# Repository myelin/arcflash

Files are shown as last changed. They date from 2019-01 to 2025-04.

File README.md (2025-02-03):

# Arcflash

A board that plugs into all Acorn Archimedes, A3000, A5000 (with adapter), and
Risc PC (with adapter) machines, allowing OS updates without opening the
machine -- or even powering it down!

[Detailed design info](DESIGN.md)

[Stardot thread](https://stardot.org.uk/forums/viewtopic.php?f=16&t=16043)

Pictures
--------

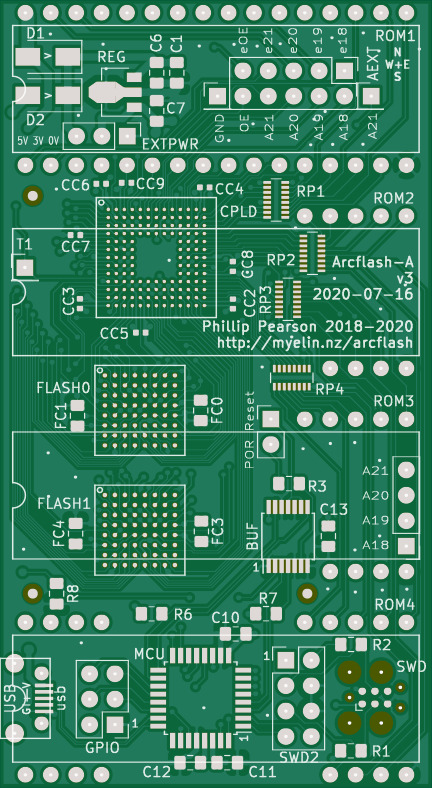
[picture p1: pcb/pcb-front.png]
PCB front


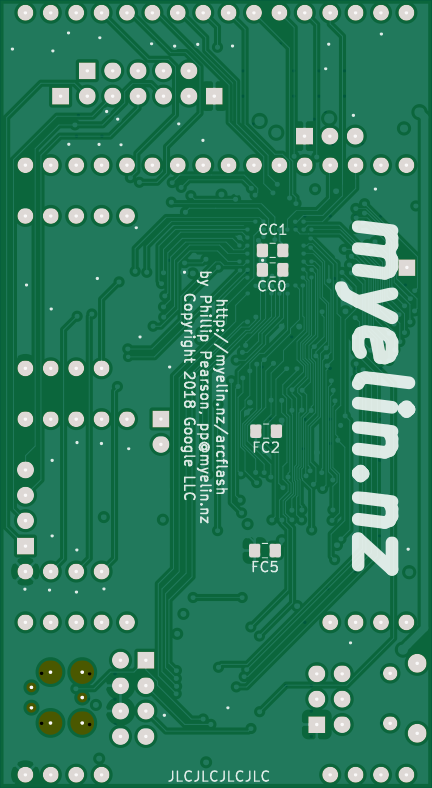
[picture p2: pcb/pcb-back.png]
PCB back


Assembly notes
--------------

For IC sockets, cut two 40-pin headers to make:

- one 2x16-pin header and one 2x4-pin headers
- four 5+4-pin headers and two 2-pin headers

Note from my employer
---------------------

This is not an officially supported Google product. This project is not
eligible for the [Google Open Source Software Vulnerability Rewards
Program](https://bughunters.google.com/open-source-security).

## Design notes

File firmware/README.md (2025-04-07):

# Firmware for Arcflash ATSAMD21E18A

This is the code that runs on the Arcflash's MCU.

It's built using the Arduino toolchain; originally using the Adafruit Circuit Playground Express variant, but now we have our own variant (see the hardware folder for details).

To build and upload, you'll need to [install arduino-cli](https://arduino.github.io/arduino-cli/installation/).

macOS: `brew install arduino-cli`

Ubuntu: `sudo apt install make; sudo snap install arduino-cli`

Run `make` for an incremental build or `make release` for a clean build.

Run `make upload` to build the code and upload it to a connected Arcflash board.

If you see "Platform not installed", "Error resolving FQBN", or an error finding a tool like `arm-none-eabi-g++`, update your cores:

~~~
arduino-cli --config-file arduino-cli.yaml core update-index
arduino-cli --config-file arduino-cli.yaml core install adafruit:samd
~~~

If you see linker errors ("Undefined reference to \`Uart::Uart(SERCOM\*, ...") on Windows, just rerun build_and_upload.py; this just seems to happen sometimes (?!)

> (2021-01-19) Note that arduino-cli 0.14.0 has a bug (*"Error during Upload: uploading error: cannot execute upload tool: fork/exec {runtime.tools.bossac-1.7.0-arduino3.path}/bossac: no such file or directory"* when it tries to upload the compiled code to the board), so if 0.15.0 isn't out yet, you'll need to:
>
> - On Windows and Linux, install a nightly build from the [arduino-cli site](https://arduino.github.io/arduino-cli/installation/)
> - On macOS, install from HEAD using Homebrew: `brew install --HEAD arduino-cli`

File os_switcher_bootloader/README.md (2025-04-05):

[Stardot thread](https://stardot.org.uk/forums/viewtopic.php?f=30&t=16420)

A bootloader that runs on the Archimedes machine and selects the OS based on
which function keys are pressed.  Also the start of a modern test ROM for 30
year old machines with possibly bad RAM or chips, or tracks that have been
eaten by leaking battery chemicals.

Getting started
---------------

Prerequisites:
- [GNU Arm Embedded Toolchain](https://developer.arm.com/downloads/-/gnu-rm) (GCC 9 dropped ARM2 support though, so you need 8-2019-q3-update)
- Python 3
- protobuf (on macOS: brew install protobuf)

On macOS: `brew install protobuf python`, and to de-quarantine the toolchain, `find /opt/gcc-arm-none-eabi-8-2019-q3-update/ -type f -perm +111 -exec xattr -d com.apple.quarantine {} \;`

On Ubuntu: `sudo apt install protobuf-compiler python3 python3-protobuf`

To build, run 'make clean all'.  This will generate switcher.rom, which can be
run on Arculator -- just put it in one of the riscos folders and set rom_set
appropriately.  (For example, if you save it as roms/riscos3/switcher.rom, you
want to have rom_set = 3 in arc.cfg.  Make sure there are no other ROM files
in the same folder.)

ROM structure
-------------

The ROM is designed to run on both Archimedes (26-bit ARMv2, MEMC) and Risc PC
(32-bit IOMD) machines.  The Archimedes code is "freestanding", handling all
IO etc itself, whereas the Risc PC code runs under a stripped-down RISC OS
build and uses RISC OS SWI commands for its UI, to access the NVRAM, etc.  To
make all this work, a number of images are concatenated to make the actual
ROM:

- 336k: RISC OS build, with modifications:
  - CPU test on startup, jumping to Archimedes bootloader if ARMv2 detected
  - No 3 second wait for special keys on boot
  - Instead of running the configured language module, run RPC bootloader
- 4 bytes: offset of RPC bootloader
- 4 bytes: offset of Arc bootloader
- Arc bootloader
- RPC bootloader

The Arc bootloader is almost but not quite position-independent code, so it's
built with a start address of 0x3854008 (Arc ROM area + 336k + 8 bytes), which
will need to be changed if the RISC OS image ever changes size.  The RPC
bootloader is copied to RAM by the final boot step in the RISC OS build, so
it's built with a start address of 0x8000.

Notes about bare metal programming for the Archimedes
-----------------------------------------------------

The initial entrypoint is \_start in start.s, which calls cstartup() in
cstartup.cc, which calls main_program() in main.cc.

The intention here is to compile everything with the latest arm-none-eabi-gcc,
rather than the ROOL DDE or GCCSDK.  It seems to be going OK so far; here are
some issues I've encountered:

- Needed to compile with -nostdlib, to avoid clashing with GCC's
  expectations for main() etc.

- Needed to compile with -fno-exceptions, otherwise the linker
  complains that it can't find \__aeabi_unwind_cpp_pr0.

- Needed to compile with -mno-thumb-interwork, otherwise the compiler
  generates "bx lr" instructions, which aren't in ARMv2.

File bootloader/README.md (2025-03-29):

# Bootloader for Arcflash ATSAMD21E18A

This is the bootloader for the Arcflash's MCU, built from [github.com/myelin/uf2-samdx1](https://github.com/myelin/uf2-samdx1).

To program into a freshly made or unresponsive Arcflash:

~~~
python3 -m pip install --user https://github.com/adafruit/Adafruit_Adalink/archive/master.zip
python3 -m adalink.main -v atsamd21g18 -p jlink -w -h bootloader-*.bin
~~~

To program into an Arcflash with a working bootloader, [install arduino-cli](https://arduino.github.io/arduino-cli/installation/) and run the following:

~~~
cp update-bootloader-*.ino bootloader.ino
arduino-cli compile --verbose --fqbn arduino:samd:adafruit_circuitplayground_m0
# Use /dev/ttyACM* (Linux) or COMn (Windows) here:
arduino-cli upload --verbose --fqbn arduino:samd:adafruit_circuitplayground_m0 --port /dev/tty.usbmodem*
~~~

To rebuild:

~~~
make clean build
~~~

To erase an unresponsive Arcflash, try this.  The `erase` command by itself won't work, as the UF2
bootloader locks the first 0x2000 bytes.

~~~
JLinkExe -device ATSAMD21G18 -if swd -speed 1000
connect
erase 0x2000,0x40000
~~~

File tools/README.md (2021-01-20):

# Arcflash tools

This folder contains example ROM build scripts for Arcflash.

First install the Python library:

~~~
(cd ../python_lib; python3 -m pip install --user -e .)
~~~

Now you can build a ROM and save it:

~~~
python3 make_arc_rom.py save myrom.bin
~~~

Or build and upload it to the Arcflash in one go:

~~~
python3 make_arc_rom.py upload
~~~

> (2021-01-19) Note that on macOS, with the first v3 Arcflash board to be built, with the latest bootloader and firmware, this seems to hang after uploading a few megabytes.  Unplugging and replugging the USB cable and rerunning should get it a bit further, and eventually you should get a "Done" message.  I can't reproduce this on Linux, and haven't tried on Windows yet.  `test_serial_comms.py` is a tester for this that forces the worst-case scenario (16MB of entirely new data) to debug this.

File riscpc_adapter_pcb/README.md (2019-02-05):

Adapter board to allow an "arcflash" A3000 ROM emulator to work on a Risc PC.

Pictures
--------

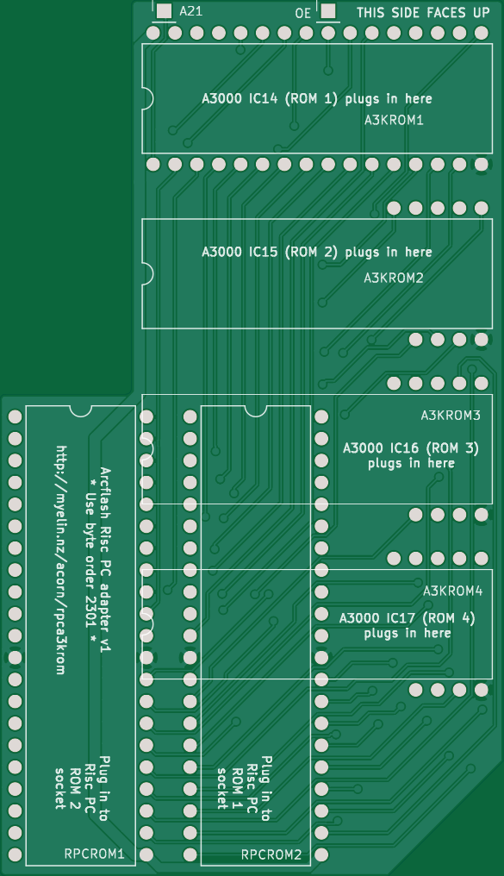
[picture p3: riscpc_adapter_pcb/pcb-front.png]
PCB front


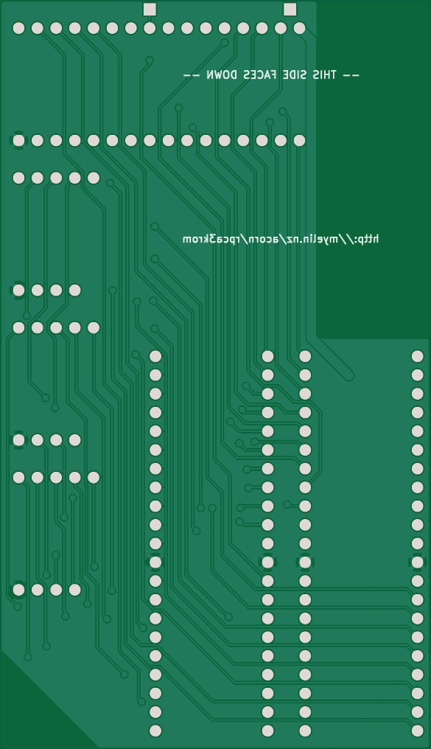
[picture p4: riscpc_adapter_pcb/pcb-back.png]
PCB back


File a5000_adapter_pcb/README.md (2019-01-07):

Adapter board to allow an "arcflash" A3000 ROM emulator to work on an A5000.

Pictures
--------

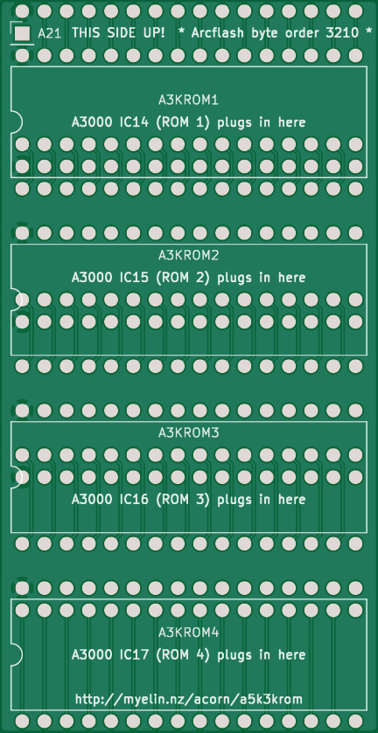
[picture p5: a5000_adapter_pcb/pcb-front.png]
PCB front


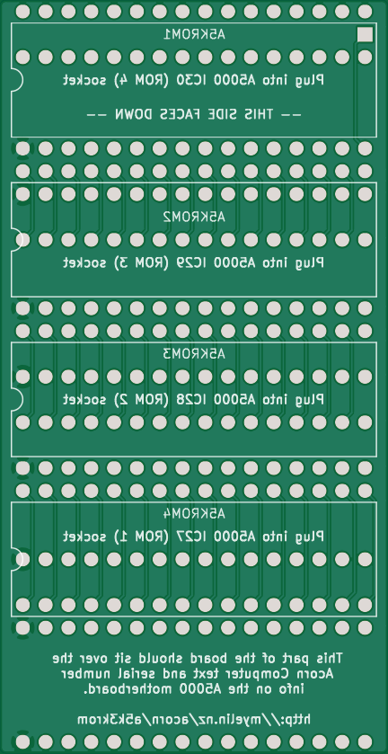
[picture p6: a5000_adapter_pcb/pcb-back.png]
PCB back


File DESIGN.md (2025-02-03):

# Arcflash Design Overview

Arcflash is a circuit board that plugs into the ROM sockets of many of the "Archimedes" series computers made by Acorn in the UK, circa 1990, running ARM2 or ARM3 processors (ARMv2 arch).
It allows uploading one or more operating system images over USB, and includes a bootloader to allow the user to select one to boot.

## Circuit design ([pcb/](pcb/))

PCB front

The OS images are stored on two 16 bit wide 8MB flash chips; `FLASH0` holds the lower two bytes of each word and `FLASH1` holds the high bytes.

A CPLD (`CPLD`) handles all the switching; it connects to the ROM socket address and data lines (via resistor packs RP1-4) and passes addresses through to the flash chips and data back to the data lines on the ROM sockets.

A microcontroller (`MCU`) provides the USB interface, so an attached computer can program OS images into the flash chips.

## CPLD gateware ([cpld/](cpld/))

The CPLD gateware's main function is to proxy the host's address bus (as seen on the ROM socket pins) over to the flash chips, and proxy data back to the host.

It also speaks a simple SPI protocol to allow the MCU to read and write from the flash, select the flash bank to expose to the host machine, and 

Finally, it listens for reads to certain "magic addresses", and implements a one-bit communication channel between the host and MCU. With proper timing, the host can bit-bang a slow serial connection.

The CPLD gateware is built using the (discontinued) Xilinx ISE 14.7 software.

## Host bootloader ([os_switcher_bootloader/](os_switcher_bootloader/))

The host bootloader runs as a bare-metal application.

It reads a proto containing information about all the OS images programmed into the flash, displays a menu, and forwards the user's OS selection to the microcontroller (over the bit-banged serial port).

See [this forum post](https://stardot.org.uk/forums/viewtopic.php?p=229976#p229976) for details on the code structure.

The host bootloader is compiled with gcc-arm-none-eabi version 8 or earlier (GCC 9 dropped ARMv2 support).

## MCU firmware ([firmware/](firmware/), [bootloader/](bootloader/))

The MCU firmware is mainly responsible for USB communication: it speaks a very simple text-based protocol that allows the remote driver software to program the flash.

It is also responsible for listening on a serial port for instructions from the host bootloader. When the user selects an OS to boot, the MCU firmware sends instructions to the CPLD to switch banks, then drives the system reset line to cause the host machine to reboot.

The MCU firmware is compiled compiled using the Arduino toolchain (using `arduino-cli`).

## Remote driver software ([python_lib/](python_lib/))

This code runs on an attached computer, to pack OS images into the correct format, and send them to an Arcflash board over USB.

The remote driver software is written in Python 3.

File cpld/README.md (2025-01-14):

# Arcflash CPLD RTL

This is the RTL for the Xilinx XC95144XL CPLD on the Arcflash board.

Build this using Xilinx ISE 14.7.  This is a discontinued product, but you can still download it.  I don't recommend using the Windows 10 version (which is a Linux VM running an old version of Oracle Linux).  If you're on Windows, use WSL2 and Ubuntu and install the Linux version instead.  To install the Linux version, google `xilinx ise 14.7 download` and download the *Full Installer for Linux* or the *Full DVD Single File Download Image*, untar somewhere, and run `./xsetup`.  If you get an error about `libncurses.so.5`, at least on Ubuntu Noble you can just `cd /usr/lib/x86_64-linux-gnu && ln -s libncurses.so.6 libncurses.so.5`, and the graphical installer will start up fine.

To build the `.svf` image: `make local`

Arcflash has no external JTAG connector; program the CPLD via the MCU: `make program`

To run the testbenches (the old Verilog one and the new Python/cocotb one), install Icarus Verilog and `cocotb`, and run: `make test2`

I run builds under Linux but test on macOS, so this means `brew install icarus-verilog gtkwave python3; python3 -m venv ~/ve; source ~/ve/bin/activate; pip3 install cocotb pytest; make test2`

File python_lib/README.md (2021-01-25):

# Arcflash

Arcflash is a flash ROM board for the Acorn Archimedes and Risc PC computers.

This is the Python support library, which lets you build your own flash
images, and program them into the memory on an Arcflash board connected over
USB.

Project homepage: http://myelin.nz/arcflash

Python library code: https://github.com/google/myelin-acorn-electron-hardware/tree/main/a3000_rom_emulator/python_lib

## Getting started

First, install the library with `pip install arcflash`.

Next, copy the following example and save it as `myrom.py`.  This assumes you have the [3QD classic rom archive](http://www.riscos.com/shop/products/101/index.htm) unpacked in a folder called `classics`.

~~~~
from arcflash.rombuild import *

FlashImage(
    roms=[
        ROM(
            tag="arthur030",
            name="Arthur 0.30",
            files=['classics/Arthur/Arthur_030'],
            size=_1M,
            cmos="arthur030",
            ),
        ROM(
            tag="arthur120",
            name="Arthur 1.20",
            files=['classics/Arthur/Arthur_120'],
            size=_1M,
            cmos="arthur120",
            ),
        ROM(
            tag="riscos201",
            name="RISC OS 2.01",
            files=['classics/RISC_OS_2/ROM_201'],
            size=_1M,
            cmos="riscos201",
        ),
        ROM(
            tag="riscos311",
            name="RISC OS 3.11",
            files=['classics/RISC_OS_3/ROM_311'],
            size=_2M,
            cmos="riscos311",
            ),
    ],
)
~~~~

Now run `python myrom.py save rom.bin` to build the flash image and save it as rom.bin.  This file should be 16MB long.  If that worked, plug in your Arcflash board and run `python myrom.py upload` to build and upload the flash image.

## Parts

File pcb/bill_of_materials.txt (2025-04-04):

Identifier	Value	Description	KiCad package	LCSC part
RP1	Pack of 8 x isolated 68R resistors	8 x 68R pack; https://www.digikey.com/product-detail/en/panasonic-electronic-components/EXB-2HV680JV/Y1680CT-ND/285367	Resistor_SMD:R_Array_Convex_8x0602	
RP2	Pack of 8 x isolated 68R resistors	8 x 68R pack; https://www.digikey.com/product-detail/en/panasonic-electronic-components/EXB-2HV680JV/Y1680CT-ND/285367	Resistor_SMD:R_Array_Convex_8x0602	
RP3	Pack of 8 x isolated 68R resistors	8 x 68R pack; https://www.digikey.com/product-detail/en/panasonic-electronic-components/EXB-2HV680JV/Y1680CT-ND/285367	Resistor_SMD:R_Array_Convex_8x0602	
RP4	Pack of 8 x isolated 68R resistors	8 x 68R pack; https://www.digikey.com/product-detail/en/panasonic-electronic-components/EXB-2HV680JV/Y1680CT-ND/285367	Resistor_SMD:R_Array_Convex_8x0602	
CC2	100n	Capacitor 0402: 100n	Capacitor_SMD:C_0402_1005Metric	
CC3	100n	Capacitor 0402: 100n	Capacitor_SMD:C_0402_1005Metric	
CC4	100n	Capacitor 0402: 100n	Capacitor_SMD:C_0402_1005Metric	
CC5	100n	Capacitor 0402: 100n	Capacitor_SMD:C_0402_1005Metric	
CC6	100n	Capacitor 0402: 100n	Capacitor_SMD:C_0402_1005Metric	
CC7	100n	Capacitor 0402: 100n	Capacitor_SMD:C_0402_1005Metric	
CC8	100n	Capacitor 0402: 100n	Capacitor_SMD:C_0402_1005Metric	
CC9	100n	Capacitor 0402: 100n	Capacitor_SMD:C_0402_1005Metric	
C10	100n	Capacitor 0805: 100n	Capacitor_SMD:C_0805_2012Metric_Pad1.15x1.40mm_HandSolder	C49678
C11	100n	Capacitor 0805: 100n	Capacitor_SMD:C_0805_2012Metric_Pad1.15x1.40mm_HandSolder	C49678
C13	100n	Capacitor 0805: 100n	Capacitor_SMD:C_0805_2012Metric_Pad1.15x1.40mm_HandSolder	C49678
FC0	100n	Capacitor 0805: 100n	Capacitor_SMD:C_0805_2012Metric_Pad1.15x1.40mm_HandSolder	C49678
FC1	100n	Capacitor 0805: 100n	Capacitor_SMD:C_0805_2012Metric_Pad1.15x1.40mm_HandSolder	C49678
FC3	100n	Capacitor 0805: 100n	Capacitor_SMD:C_0805_2012Metric_Pad1.15x1.40mm_HandSolder	C49678
FC4	100n	Capacitor 0805: 100n	Capacitor_SMD:C_0805_2012Metric_Pad1.15x1.40mm_HandSolder	C49678
CC0	100n NF	Capacitor 0805: 100n NF	Capacitor_SMD:C_0805_2012Metric_Pad1.15x1.40mm_HandSolder	
CC1	100n NF	Capacitor 0805: 100n NF	Capacitor_SMD:C_0805_2012Metric_Pad1.15x1.40mm_HandSolder	
FC2	100n NF	Capacitor 0805: 100n NF	Capacitor_SMD:C_0805_2012Metric_Pad1.15x1.40mm_HandSolder	
FC5	100n NF	Capacitor 0805: 100n NF	Capacitor_SMD:C_0805_2012Metric_Pad1.15x1.40mm_HandSolder	
C1	10u	Capacitor 0805: 10u	Capacitor_SMD:C_0805_2012Metric_Pad1.15x1.40mm_HandSolder	
C6	1u	Capacitor 0805: 1u	Capacitor_SMD:C_0805_2012Metric_Pad1.15x1.40mm_HandSolder	C28323
C7	1u	Capacitor 0805: 1u	Capacitor_SMD:C_0805_2012Metric_Pad1.15x1.40mm_HandSolder	C28323
C12	1u	Capacitor 0805: 1u	Capacitor_SMD:C_0805_2012Metric_Pad1.15x1.40mm_HandSolder	C28323
D1	S1ATR	Diode Rectifier; https://www.digikey.com/products/en?keywords=1655-1502-1-ND	Diode_SMD:D_SMA	
D2	S1ATR NF	Diode Rectifier; https://www.digikey.com/products/en?keywords=1655-1502-1-ND	Diode_SMD:D_SMA	
MCU	ATSAMD21E18A-AU	IC ARM MCU; https://www.digikey.com/products/en?keywords=ATSAMD21E18A-AU-ND	Package_QFP:TQFP-32_7x7mm_P0.8mm	
CPLD	XC95144XL-10CSG144	IC CPLD Xilinx 144MC	myelin-kicad:xilinx_csg144	
REG	AP7365-33YG-XX	IC LDO 3.3V regulator; https://www.digikey.com/products/en?keywords=AP7365-33YG-13DICT-ND	Package_TO_SOT_SMD:SOT-89-3	
BUF	74LVC125PW	IC buffer 4-bit OC LVT; https://www.digikey.com/product-detail/en/74LVT125PW%2c118/1727-3115-1-ND	Package_SO:TSSOP-14_4.4x5mm_P0.65mm	
FLASH0	S29GL064S70DHI010	IC flash 64Mbit; https://www.digikey.com/products/en?keywords=2015-S29GL064S70DHI010-ND	myelin-kicad:cypress_lae064_fbga	
FLASH1	S29GL064S70DHI010	IC flash 64Mbit; https://www.digikey.com/products/en?keywords=2015-S29GL064S70DHI010-ND	myelin-kicad:cypress_lae064_fbga	
ROM1	ROM header	Pin adapter to emulate a 600mil 32-pin DIP; round pin header strip from Aliexpress	myelin-kicad:dip32_rom	
ROM2	ROM header	Pin adapter to emulate a 600mil 32-pin DIP; round pin header strip from Aliexpress	myelin-kicad:dip32_rom_data_only	
ROM3	ROM header	Pin adapter to emulate a 600mil 32-pin DIP; round pin header strip from Aliexpress	myelin-kicad:dip32_rom_data_only	
ROM4	ROM header	Pin adapter to emulate a 600mil 32-pin DIP; round pin header strip from Aliexpress	myelin-kicad:dip32_rom_data_only	
AEXT2	Addresses	Pin header	Connector_PinHeader_2.54mm:PinHeader_1x04_P2.54mm_Vertical	
AEXT	Extras	Pin header	Connector_PinHeader_2.54mm:PinHeader_2x05_P2.54mm_Vertical	
AEXTGND	Ground	Pin header	Connector_PinHeader_2.54mm:PinHeader_1x01_P2.54mm_Vertical	
T1	rom_5V	Pin header	Connector_PinHeader_2.54mm:PinHeader_1x01_P2.54mm_Vertical	
A21	rom_A19	Pin header	Connector_PinHeader_2.54mm:PinHeader_1x01_P2.54mm_Vertical	
RESET	reset/POR	Pin header - 1x2 0.1 inch male	Connector_PinHeader_2.54mm:PinHeader_1x02_P2.54mm_Vertical	
GPIO	gpio	Pin header NF	Connector_PinHeader_2.54mm:PinHeader_2x03_P2.54mm_Vertical	
SWD2	swd	Pin header NF	Connector_PinHeader_2.54mm:PinHeader_2x04_P2.54mm_Vertical	
EXTPWR	ext pwr	Pin header NF - 1x3 0.1 inch male	Connector_PinHeader_2.54mm:PinHeader_1x03_P2.54mm_Vertical	
R3	100R	Resistor 0805: 100R	Resistor_SMD:R_0805_2012Metric_Pad1.15x1.40mm_HandSolder	
R1	10k	Resistor 0805: 10k	Resistor_SMD:R_0805_2012Metric_Pad1.15x1.40mm_HandSolder	C17414
R6	10k	Resistor 0805: 10k	Resistor_SMD:R_0805_2012Metric_Pad1.15x1.40mm_HandSolder	C17414
R7	10k	Resistor 0805: 10k	Resistor_SMD:R_0805_2012Metric_Pad1.15x1.40mm_HandSolder	C17414
R8	10k	Resistor 0805: 10k	Resistor_SMD:R_0805_2012Metric_Pad1.15x1.40mm_HandSolder	C17414
R2	1k	Resistor 0805: 1k	Resistor_SMD:R_0805_2012Metric_Pad1.15x1.40mm_HandSolder	C17513
USB	usb	Socket Micro USB, Molex 1050170001; https://www.digikey.com/products/en?keywords=WM1399CT-ND	myelin-kicad:micro_usb_b_smd_molex

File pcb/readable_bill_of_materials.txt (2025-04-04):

This is the human-readable bill of materials.
See bill_of_materials.txt for a terser version suitable for spreadsheet import.

RP1
- Value: Pack of 8 x isolated 68R resistors
- Description: 8 x 68R pack; https://www.digikey.com/product-detail/en/panasonic-electronic-components/EXB-2HV680JV/Y1680CT-ND/285367
- KiCad package: Resistor_SMD:R_Array_Convex_8x0602

RP2
- Value: Pack of 8 x isolated 68R resistors
- Description: 8 x 68R pack; https://www.digikey.com/product-detail/en/panasonic-electronic-components/EXB-2HV680JV/Y1680CT-ND/285367
- KiCad package: Resistor_SMD:R_Array_Convex_8x0602

RP3
- Value: Pack of 8 x isolated 68R resistors
- Description: 8 x 68R pack; https://www.digikey.com/product-detail/en/panasonic-electronic-components/EXB-2HV680JV/Y1680CT-ND/285367
- KiCad package: Resistor_SMD:R_Array_Convex_8x0602

RP4
- Value: Pack of 8 x isolated 68R resistors
- Description: 8 x 68R pack; https://www.digikey.com/product-detail/en/panasonic-electronic-components/EXB-2HV680JV/Y1680CT-ND/285367
- KiCad package: Resistor_SMD:R_Array_Convex_8x0602

CC2
- Value: 100n
- Description: Capacitor 0402: 100n
- KiCad package: Capacitor_SMD:C_0402_1005Metric

CC3
- Value: 100n
- Description: Capacitor 0402: 100n
- KiCad package: Capacitor_SMD:C_0402_1005Metric

CC4
- Value: 100n
- Description: Capacitor 0402: 100n
- KiCad package: Capacitor_SMD:C_0402_1005Metric

CC5
- Value: 100n
- Description: Capacitor 0402: 100n
- KiCad package: Capacitor_SMD:C_0402_1005Metric

CC6
- Value: 100n
- Description: Capacitor 0402: 100n
- KiCad package: Capacitor_SMD:C_0402_1005Metric

CC7
- Value: 100n
- Description: Capacitor 0402: 100n
- KiCad package: Capacitor_SMD:C_0402_1005Metric

CC8
- Value: 100n
- Description: Capacitor 0402: 100n
- KiCad package: Capacitor_SMD:C_0402_1005Metric

CC9
- Value: 100n
- Description: Capacitor 0402: 100n
- KiCad package: Capacitor_SMD:C_0402_1005Metric

C10
- Value: 100n
- Description: Capacitor 0805: 100n
- KiCad package: Capacitor_SMD:C_0805_2012Metric_Pad1.15x1.40mm_HandSolder

C11
- Value: 100n
- Description: Capacitor 0805: 100n
- KiCad package: Capacitor_SMD:C_0805_2012Metric_Pad1.15x1.40mm_HandSolder

C13
- Value: 100n
- Description: Capacitor 0805: 100n
- KiCad package: Capacitor_SMD:C_0805_2012Metric_Pad1.15x1.40mm_HandSolder

FC0
- Value: 100n
- Description: Capacitor 0805: 100n
- KiCad package: Capacitor_SMD:C_0805_2012Metric_Pad1.15x1.40mm_HandSolder

FC1
- Value: 100n
- Description: Capacitor 0805: 100n
- KiCad package: Capacitor_SMD:C_0805_2012Metric_Pad1.15x1.40mm_HandSolder

FC3
- Value: 100n
- Description: Capacitor 0805: 100n
- KiCad package: Capacitor_SMD:C_0805_2012Metric_Pad1.15x1.40mm_HandSolder

FC4
- Value: 100n
- Description: Capacitor 0805: 100n
- KiCad package: Capacitor_SMD:C_0805_2012Metric_Pad1.15x1.40mm_HandSolder

CC0
- Value: 100n NF
- Description: Capacitor 0805: 100n NF
- KiCad package: Capacitor_SMD:C_0805_2012Metric_Pad1.15x1.40mm_HandSolder

CC1
- Value: 100n NF
- Description: Capacitor 0805: 100n NF
- KiCad package: Capacitor_SMD:C_0805_2012Metric_Pad1.15x1.40mm_HandSolder

FC2
- Value: 100n NF
- Description: Capacitor 0805: 100n NF
- KiCad package: Capacitor_SMD:C_0805_2012Metric_Pad1.15x1.40mm_HandSolder

FC5
- Value: 100n NF
- Description: Capacitor 0805: 100n NF
- KiCad package: Capacitor_SMD:C_0805_2012Metric_Pad1.15x1.40mm_HandSolder

C1
- Value: 10u
- Description: Capacitor 0805: 10u
- KiCad package: Capacitor_SMD:C_0805_2012Metric_Pad1.15x1.40mm_HandSolder

C6
- Value: 1u
- Description: Capacitor 0805: 1u
- KiCad package: Capacitor_SMD:C_0805_2012Metric_Pad1.15x1.40mm_HandSolder

C7
- Value: 1u
- Description: Capacitor 0805: 1u
- KiCad package: Capacitor_SMD:C_0805_2012Metric_Pad1.15x1.40mm_HandSolder

C12
- Value: 1u
- Description: Capacitor 0805: 1u
- KiCad package: Capacitor_SMD:C_0805_2012Metric_Pad1.15x1.40mm_HandSolder

D1
- Value: S1ATR
- Description: Diode Rectifier; https://www.digikey.com/products/en?keywords=1655-1502-1-ND
- KiCad package: Diode_SMD:D_SMA

D2
- Value: S1ATR NF
- Description: Diode Rectifier; https://www.digikey.com/products/en?keywords=1655-1502-1-ND
- KiCad package: Diode_SMD:D_SMA

MCU
- Value: ATSAMD21E18A-AU
- Description: IC ARM MCU; https://www.digikey.com/products/en?keywords=ATSAMD21E18A-AU-ND
- KiCad package: Package_QFP:TQFP-32_7x7mm_P0.8mm

CPLD
- Value: XC95144XL-10CSG144
- Description: IC CPLD Xilinx 144MC
- KiCad package: myelin-kicad:xilinx_csg144

REG
- Value: AP7365-33YG-XX
- Description: IC LDO 3.3V regulator; https://www.digikey.com/products/en?keywords=AP7365-33YG-13DICT-ND
- KiCad package: Package_TO_SOT_SMD:SOT-89-3

BUF
- Value: 74LVC125PW
- Description: IC buffer 4-bit OC LVT; https://www.digikey.com/product-detail/en/74LVT125PW%2c118/1727-3115-1-ND
- KiCad package: Package_SO:TSSOP-14_4.4x5mm_P0.65mm

FLASH0
- Value: S29GL064S70DHI010
- Description: IC flash 64Mbit; https://www.digikey.com/products/en?keywords=2015-S29GL064S70DHI010-ND
- KiCad package: myelin-kicad:cypress_lae064_fbga

FLASH1
- Value: S29GL064S70DHI010
- Description: IC flash 64Mbit; https://www.digikey.com/products/en?keywords=2015-S29GL064S70DHI010-ND
- KiCad package: myelin-kicad:cypress_lae064_fbga

ROM1
- Value: ROM header
- Description: Pin adapter to emulate a 600mil 32-pin DIP; round pin header strip from Aliexpress
- KiCad package: myelin-kicad:dip32_rom

ROM2
- Value: ROM header
- Description: Pin adapter to emulate a 600mil 32-pin DIP; round pin header strip from Aliexpress
- KiCad package: myelin-kicad:dip32_rom_data_only

ROM3
- Value: ROM header
- Description: Pin adapter to emulate a 600mil 32-pin DIP; round pin header strip from Aliexpress
- KiCad package: myelin-kicad:dip32_rom_data_only

ROM4
- Value: ROM header
- Description: Pin adapter to emulate a 600mil 32-pin DIP; round pin header strip from Aliexpress
- KiCad package: myelin-kicad:dip32_rom_data_only

AEXT2
- Value: Addresses
- Description: Pin header
- KiCad package: Connector_PinHeader_2.54mm:PinHeader_1x04_P2.54mm_Vertical

AEXT
- Value: Extras
- Description: Pin header
- KiCad package: Connector_PinHeader_2.54mm:PinHeader_2x05_P2.54mm_Vertical

AEXTGND
- Value: Ground
- Description: Pin header
- KiCad package: Connector_PinHeader_2.54mm:PinHeader_1x01_P2.54mm_Vertical

T1
- Value: rom_5V
- Description: Pin header
- KiCad package: Connector_PinHeader_2.54mm:PinHeader_1x01_P2.54mm_Vertical

A21
- Value: rom_A19
- Description: Pin header
- KiCad package: Connector_PinHeader_2.54mm:PinHeader_1x01_P2.54mm_Vertical

RESET
- Value: reset/POR
- Description: Pin header - 1x2 0.1 inch male
- KiCad package: Connector_PinHeader_2.54mm:PinHeader_1x02_P2.54mm_Vertical

GPIO
- Value: gpio
- Description: Pin header NF
- KiCad package: Connector_PinHeader_2.54mm:PinHeader_2x03_P2.54mm_Vertical

SWD2
- Value: swd
- Description: Pin header NF
- KiCad package: Connector_PinHeader_2.54mm:PinHeader_2x04_P2.54mm_Vertical

EXTPWR
- Value: ext pwr
- Description: Pin header NF - 1x3 0.1 inch male
- KiCad package: Connector_PinHeader_2.54mm:PinHeader_1x03_P2.54mm_Vertical

R3
- Value: 100R
- Description: Resistor 0805: 100R
- KiCad package: Resistor_SMD:R_0805_2012Metric_Pad1.15x1.40mm_HandSolder

R1
- Value: 10k
- Description: Resistor 0805: 10k
- KiCad package: Resistor_SMD:R_0805_2012Metric_Pad1.15x1.40mm_HandSolder

R6
- Value: 10k
- Description: Resistor 0805: 10k
- KiCad package: Resistor_SMD:R_0805_2012Metric_Pad1.15x1.40mm_HandSolder

R7
- Value: 10k
- Description: Resistor 0805: 10k
- KiCad package: Resistor_SMD:R_0805_2012Metric_Pad1.15x1.40mm_HandSolder

R8
- Value: 10k
- Description: Resistor 0805: 10k
- KiCad package: Resistor_SMD:R_0805_2012Metric_Pad1.15x1.40mm_HandSolder

R2
- Value: 1k
- Description: Resistor 0805: 1k
- KiCad package: Resistor_SMD:R_0805_2012Metric_Pad1.15x1.40mm_HandSolder

USB
- Value: usb
- Description: Socket Micro USB, Molex 1050170001; https://www.digikey.com/products/en?keywords=WM1399CT-ND
- KiCad package: myelin-kicad:micro_usb_b_smd_molex

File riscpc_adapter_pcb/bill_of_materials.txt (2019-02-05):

Identifier	Value	Description	KiCad package
A21			Connector_PinHeader_2.54mm:PinHeader_1x01_P2.54mm_Vertical
A3KROM1	ROM header	Adapter to emulate a 600mil 32-pin DIP, e.g. Digikey ???	myelin-kicad:dip32_rom
A3KROM2	ROM header	Adapter to emulate a 600mil 32-pin DIP, e.g. Digikey ???	myelin-kicad:dip32_rom_data_only
A3KROM3	ROM header	Adapter to emulate a 600mil 32-pin DIP, e.g. Digikey ???	myelin-kicad:dip32_rom_data_only
A3KROM4	ROM header	Adapter to emulate a 600mil 32-pin DIP, e.g. Digikey ???	myelin-kicad:dip32_rom_data_only
OE			Connector_PinHeader_2.54mm:PinHeader_1x01_P2.54mm_Vertical
RPCROM1	ROM header	Adapter to emulate a 600mil 42-pin DIP, e.g. Digikey ???	myelin-kicad:dip42_rom
RPCROM2	ROM header	Adapter to emulate a 600mil 42-pin DIP, e.g. Digikey ???	myelin-kicad:dip42_rom

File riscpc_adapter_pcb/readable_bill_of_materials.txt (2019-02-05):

This is the human-readable bill of materials.
See bill_of_materials.txt for a terser version suitable for spreadsheet import.

A21
- Value: 
- Description: 
- KiCad package: Connector_PinHeader_2.54mm:PinHeader_1x01_P2.54mm_Vertical

A3KROM1
- Value: ROM header
- Description: Adapter to emulate a 600mil 32-pin DIP, e.g. Digikey ???
- KiCad package: myelin-kicad:dip32_rom

A3KROM2
- Value: ROM header
- Description: Adapter to emulate a 600mil 32-pin DIP, e.g. Digikey ???
- KiCad package: myelin-kicad:dip32_rom_data_only

A3KROM3
- Value: ROM header
- Description: Adapter to emulate a 600mil 32-pin DIP, e.g. Digikey ???
- KiCad package: myelin-kicad:dip32_rom_data_only

A3KROM4
- Value: ROM header
- Description: Adapter to emulate a 600mil 32-pin DIP, e.g. Digikey ???
- KiCad package: myelin-kicad:dip32_rom_data_only

OE
- Value: 
- Description: 
- KiCad package: Connector_PinHeader_2.54mm:PinHeader_1x01_P2.54mm_Vertical

RPCROM1
- Value: ROM header
- Description: Adapter to emulate a 600mil 42-pin DIP, e.g. Digikey ???
- KiCad package: myelin-kicad:dip42_rom

RPCROM2
- Value: ROM header
- Description: Adapter to emulate a 600mil 42-pin DIP, e.g. Digikey ???
- KiCad package: myelin-kicad:dip42_rom

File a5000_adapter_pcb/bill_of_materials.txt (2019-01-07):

Identifier	Value	Description	KiCad package
A21			Connector_PinHeader_2.54mm:PinHeader_1x01_P2.54mm_Vertical
A3KROM1	ROM header	Adapter to emulate a 600mil 32-pin DIP, e.g. Digikey ???	myelin-kicad:dip32_rom
A3KROM2	ROM header	Adapter to emulate a 600mil 32-pin DIP, e.g. Digikey ???	myelin-kicad:dip32_rom
A3KROM3	ROM header	Adapter to emulate a 600mil 32-pin DIP, e.g. Digikey ???	myelin-kicad:dip32_rom
A3KROM4	ROM header	Adapter to emulate a 600mil 32-pin DIP, e.g. Digikey ???	myelin-kicad:dip32_rom
A5KROM1	ROM header	Adapter to emulate a 600mil 32-pin DIP, e.g. Digikey ???	myelin-kicad:dip32_rom_bottom
A5KROM2	ROM header	Adapter to emulate a 600mil 32-pin DIP, e.g. Digikey ???	myelin-kicad:dip32_rom_bottom
A5KROM3	ROM header	Adapter to emulate a 600mil 32-pin DIP, e.g. Digikey ???	myelin-kicad:dip32_rom_bottom
A5KROM4	ROM header	Adapter to emulate a 600mil 32-pin DIP, e.g. Digikey ???	myelin-kicad:dip32_rom_bottom

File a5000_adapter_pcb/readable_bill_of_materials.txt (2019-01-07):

This is the human-readable bill of materials.
See bill_of_materials.txt for a terser version suitable for spreadsheet import.

A21
- Value: 
- Description: 
- KiCad package: Connector_PinHeader_2.54mm:PinHeader_1x01_P2.54mm_Vertical

A3KROM1
- Value: ROM header
- Description: Adapter to emulate a 600mil 32-pin DIP, e.g. Digikey ???
- KiCad package: myelin-kicad:dip32_rom

A3KROM2
- Value: ROM header
- Description: Adapter to emulate a 600mil 32-pin DIP, e.g. Digikey ???
- KiCad package: myelin-kicad:dip32_rom

A3KROM3
- Value: ROM header
- Description: Adapter to emulate a 600mil 32-pin DIP, e.g. Digikey ???
- KiCad package: myelin-kicad:dip32_rom

A3KROM4
- Value: ROM header
- Description: Adapter to emulate a 600mil 32-pin DIP, e.g. Digikey ???
- KiCad package: myelin-kicad:dip32_rom

A5KROM1
- Value: ROM header
- Description: Adapter to emulate a 600mil 32-pin DIP, e.g. Digikey ???
- KiCad package: myelin-kicad:dip32_rom_bottom

A5KROM2
- Value: ROM header
- Description: Adapter to emulate a 600mil 32-pin DIP, e.g. Digikey ???
- KiCad package: myelin-kicad:dip32_rom_bottom

A5KROM3
- Value: ROM header
- Description: Adapter to emulate a 600mil 32-pin DIP, e.g. Digikey ???
- KiCad package: myelin-kicad:dip32_rom_bottom

A5KROM4
- Value: ROM header
- Description: Adapter to emulate a 600mil 32-pin DIP, e.g. Digikey ???
- KiCad package: myelin-kicad:dip32_rom_bottom

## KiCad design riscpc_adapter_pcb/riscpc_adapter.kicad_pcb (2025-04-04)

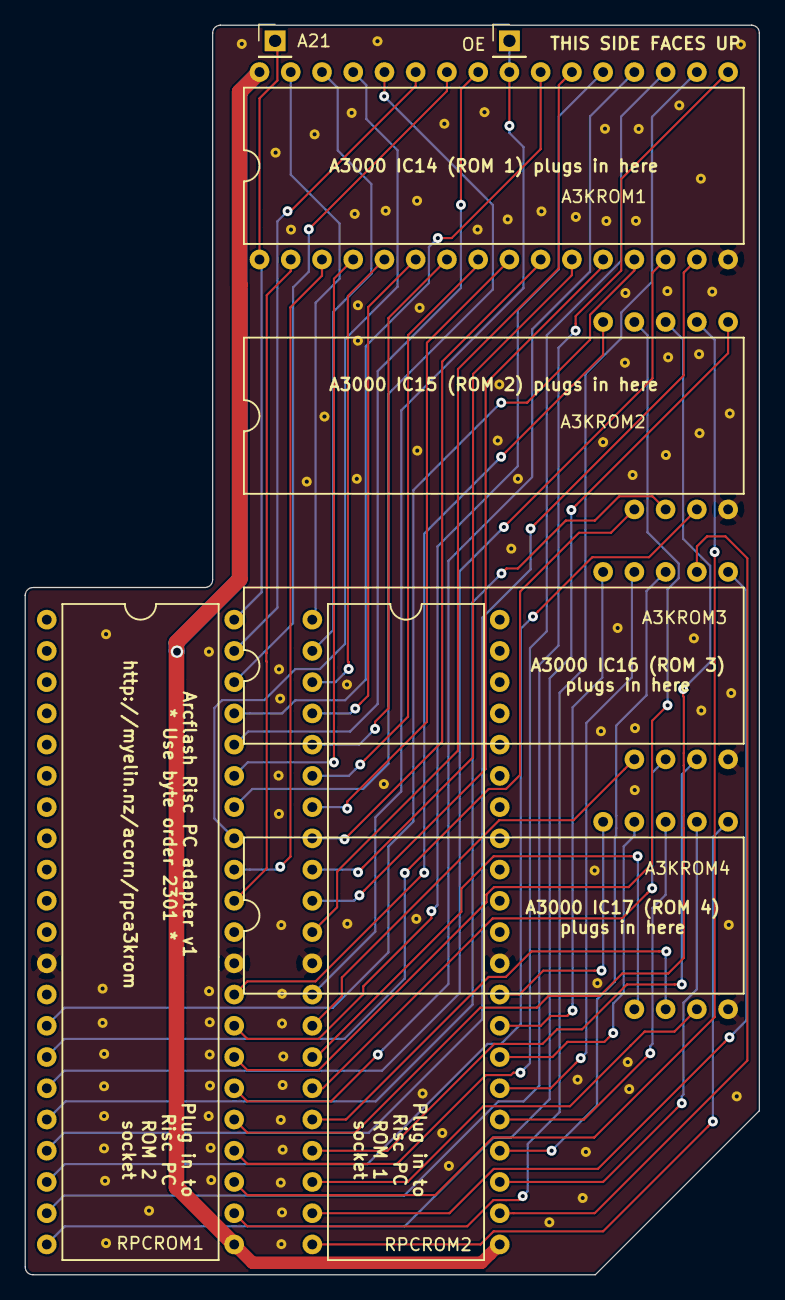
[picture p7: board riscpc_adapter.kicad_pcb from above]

Board: 2 copper layers, 59.7 x 101.6 mm, 108 parts (0 on the bottom side), 56 nets.

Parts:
A3KROM1: ROM header; dip32_rom
A3KROM2, A3KROM3, A3KROM4: ROM header; dip32_rom_data_only
A21: PinHeader_1x01_P2.54mm_Vertical
OE: PinHeader_1x01_P2.54mm_Vertical
RPCROM1, RPCROM2: ROM header; dip42_rom
staple_single1, staple_single2, staple_single3, staple_single4, staple_single5, staple_single6, staple_single7, staple_single8, staple_single9, staple_single10, staple_single11, staple_single12, staple_single13, staple_single14, staple_single15, staple_single16, staple_single17, staple_single18, staple_single19, staple_single20, staple_single21, staple_single22, staple_single23, staple_single24, staple_single25, staple_single26, staple_single27, staple_single28, staple_single29, staple_single30, staple_single31, staple_single32, staple_single33, staple_single34, staple_single35, staple_single36, staple_single37, staple_single38, staple_single39, staple_single40, staple_single41, staple_single42, staple_single43, staple_single44, staple_single45, staple_single46, staple_single47, staple_single48, staple_single49, staple_single50, staple_single51, staple_single52, staple_single53, staple_single54, staple_single55, staple_single56, staple_single57, staple_single58, staple_single59, staple_single60, staple_single61, staple_single62, staple_single63, staple_single64, staple_single65, staple_single66, staple_single67, staple_single68, staple_single69, staple_single70, staple_single71, staple_single72, staple_single73, staple_single74, staple_single75, staple_single76, staple_single77, staple_single78, staple_single79, staple_single80, staple_single81, staple_single82, staple_single83, staple_single84, staple_single85, staple_single86, staple_single87, staple_single88, staple_single89, staple_single90, staple_single91, staple_single92, staple_single93, staple_single94, staple_single95, staple_single96, staple_single97, staple_single98, staple_single99, staple_single100: via_single

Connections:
5V: A3KROM1.32, RPCROM1.22, RPCROM2.22
A0: A3KROM1.12, RPCROM2.10
A1: A3KROM1.11, RPCROM2.9
A2: A3KROM1.10, RPCROM2.8
A3: A3KROM1.9, RPCROM2.7
A4: A3KROM1.8, RPCROM2.6
A5: A3KROM1.7, RPCROM2.5
A6: A3KROM1.6, RPCROM2.4
A7: A3KROM1.5, RPCROM2.3
A8: A3KROM1.27, RPCROM1.41
A9: A3KROM1.26, RPCROM1.40
A10: A3KROM1.23, RPCROM1.39
A11: A3KROM1.25, RPCROM1.38
A12: A3KROM1.4, RPCROM1.37
A13: A3KROM1.28, RPCROM1.36
A14: A3KROM1.29, RPCROM1.35
A15: A3KROM1.3, RPCROM1.34
A16: A3KROM1.2, RPCROM1.33
A17: A3KROM1.30, RPCROM2.2
A18: A3KROM1.31, RPCROM2.1
A19: A3KROM1.1, A21.1, RPCROM1.42
D0: A3KROM1.13, RPCROM1.14
D1: A3KROM1.14, RPCROM1.16
D2: A3KROM1.15, RPCROM1.18
D3: A3KROM1.17, RPCROM1.20
D4: A3KROM1.18, RPCROM1.23
D5: A3KROM1.19, RPCROM1.25
D6: A3KROM1.20, RPCROM1.27
D7: A3KROM1.21, RPCROM1.29
D8: A3KROM2.13, RPCROM1.15
D9: A3KROM2.14, RPCROM1.17
D10: A3KROM2.15, RPCROM1.19
D11: A3KROM2.17, RPCROM1.21
D12: A3KROM2.18, RPCROM1.24
D13: A3KROM2.19, RPCROM1.26
D14: A3KROM2.20, RPCROM1.28
D15: A3KROM2.21, RPCROM1.30
D16: A3KROM3.13, RPCROM2.14
D17: A3KROM3.14, RPCROM2.16
D18: A3KROM3.15, RPCROM2.18
D19: A3KROM3.17, RPCROM2.20
D20: A3KROM3.18, RPCROM2.23
D21: A3KROM3.19, RPCROM2.25
D22: A3KROM3.20, RPCROM2.27
D23: A3KROM3.21, RPCROM2.29
D24: A3KROM4.13, RPCROM2.15
D25: A3KROM4.14, RPCROM2.17
D26: A3KROM4.15, RPCROM2.19
D27: A3KROM4.17, RPCROM2.21
D28: A3KROM4.18, RPCROM2.24
D29: A3KROM4.19, RPCROM2.26
D30: A3KROM4.20, RPCROM2.28
D31: A3KROM4.21, RPCROM2.30
GND: A3KROM1.16, A3KROM2.16, A3KROM3.16, A3KROM4.16, RPCROM1.12, RPCROM1.31, RPCROM2.12, RPCROM2.31, staple_single1.1, staple_single2.1, staple_single3.1, staple_single4.1, staple_single5.1, staple_single6.1, staple_single7.1, staple_single8.1, staple_single9.1, staple_single10.1, staple_single11.1, staple_single12.1, staple_single13.1, staple_single14.1, staple_single15.1, staple_single16.1, staple_single17.1, staple_single18.1, staple_single19.1, staple_single20.1, staple_single21.1, staple_single22.1, staple_single23.1, staple_single24.1, staple_single25.1, staple_single26.1, staple_single27.1, staple_single28.1, staple_single29.1, staple_single30.1, staple_single31.1, staple_single32.1, staple_single33.1, staple_single34.1, staple_single35.1, staple_single36.1, staple_single37.1, staple_single38.1, staple_single39.1, staple_single40.1, staple_single41.1, staple_single42.1, staple_single43.1, staple_single44.1, staple_single45.1, staple_single46.1, staple_single47.1, staple_single48.1, staple_single49.1, staple_single50.1, staple_single51.1, staple_single52.1, staple_single53.1, staple_single54.1, staple_single55.1, staple_single56.1, staple_single57.1, staple_single58.1, staple_single59.1, staple_single60.1, staple_single61.1, staple_single62.1, staple_single63.1, staple_single64.1, staple_single65.1, staple_single66.1, staple_single67.1, staple_single68.1, staple_single69.1, staple_single70.1, staple_single71.1, staple_single72.1, staple_single73.1, staple_single74.1, staple_single75.1, staple_single76.1, staple_single77.1, staple_single78.1, staple_single79.1, staple_single80.1, staple_single81.1, staple_single82.1, staple_single83.1, staple_single84.1, staple_single85.1, staple_single86.1, staple_single87.1, staple_single88.1, staple_single89.1, staple_single90.1, staple_single91.1, staple_single92.1, staple_single93.1, staple_single94.1, staple_single95.1, staple_single96.1, staple_single97.1, staple_single98.1, staple_single99.1, staple_single100.1
nCS: A3KROM1.22, RPCROM2.11
nOE: A3KROM1.24, OE.1, RPCROM2.13

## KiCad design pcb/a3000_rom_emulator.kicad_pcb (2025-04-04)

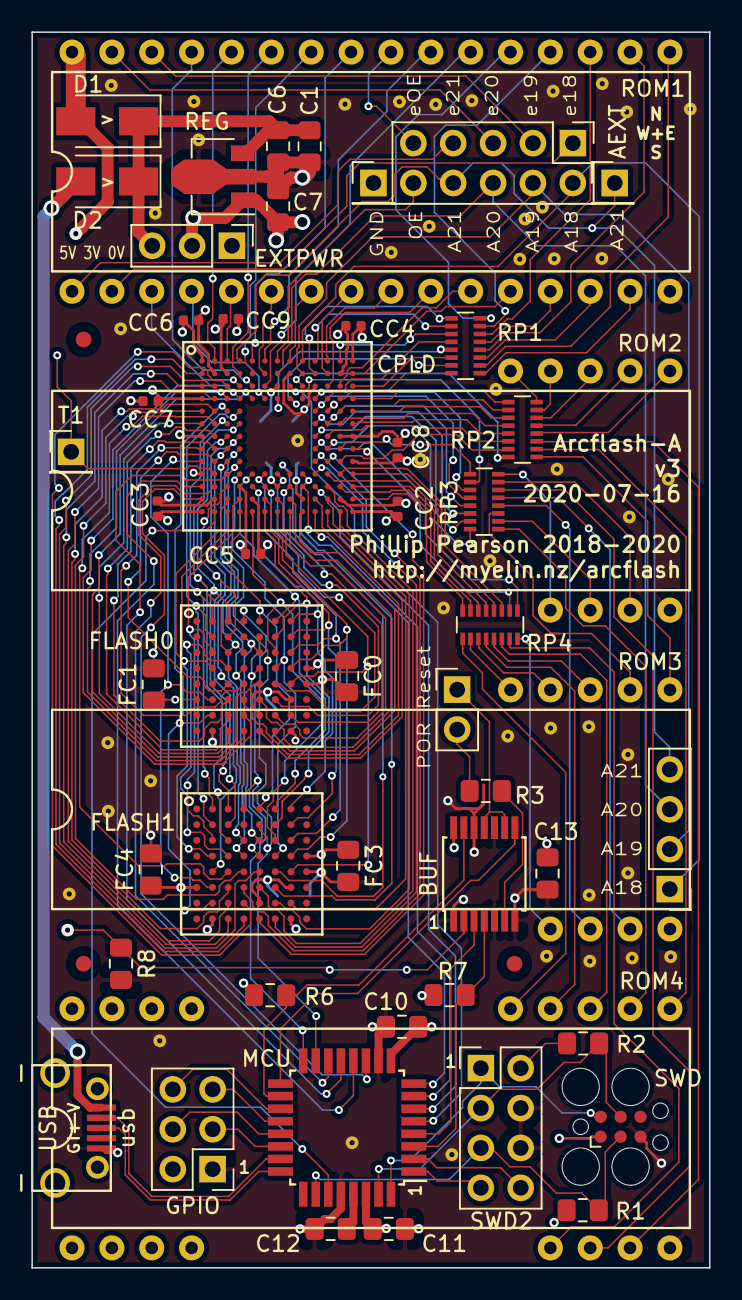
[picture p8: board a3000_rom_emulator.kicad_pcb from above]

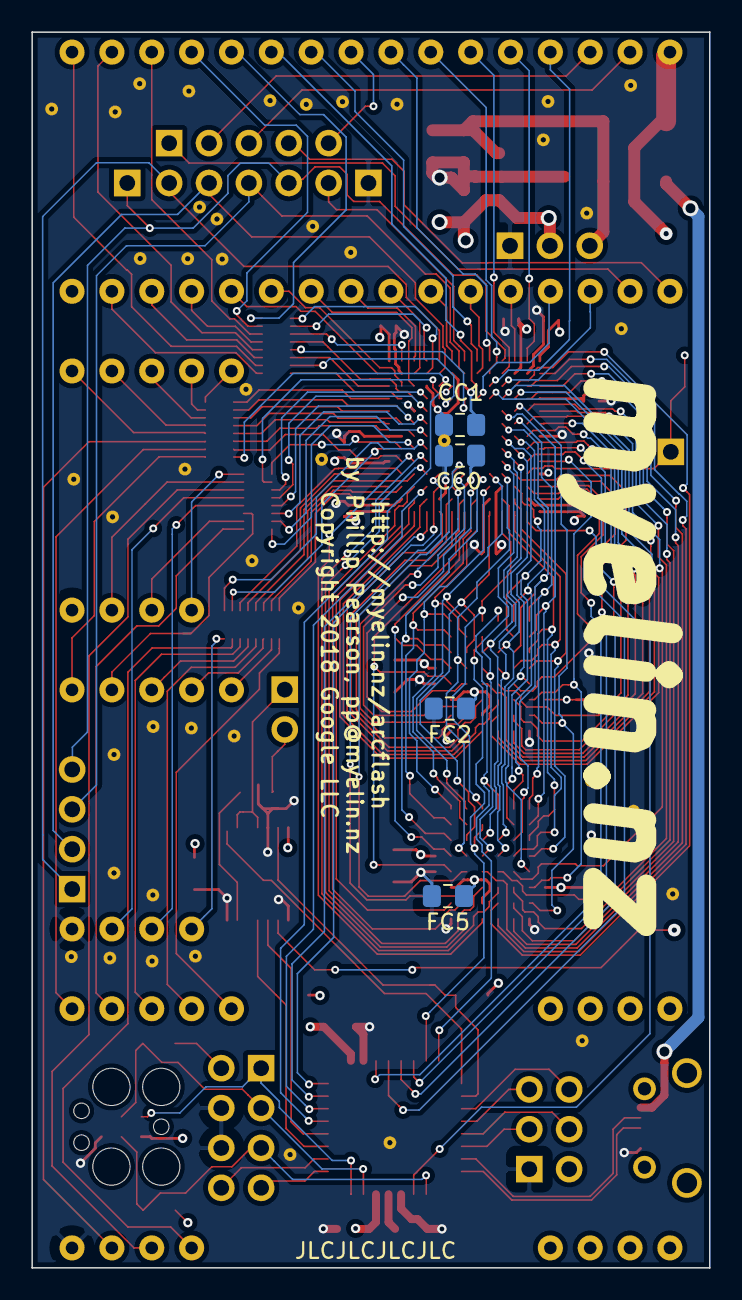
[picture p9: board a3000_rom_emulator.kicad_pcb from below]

Board: 4 copper layers, 43.2 x 78.7 mm, 112 parts (4 on the bottom side), 183 nets.

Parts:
A21: rom_A19; PinHeader_1x01_P2.54mm_Vertical
AEXT: Extras; PinHeader_2x05_P2.54mm_Vertical
AEXT2: Addresses; PinHeader_1x04_P2.54mm_Vertical
AEXTGND: Ground; PinHeader_1x01_P2.54mm_Vertical
BUF: 74LVC125PW; TSSOP-14_4.4x5mm_P0.65mm
C1: 10u; C_0805_2012Metric_Pad1.15x1.40mm_HandSolder
C6, C7, C12: 1u; C_0805_2012Metric_Pad1.15x1.40mm_HandSolder
C10, C11, C13: 100n; C_0805_2012Metric_Pad1.15x1.40mm_HandSolder
CC0, CC1: 100n; C_0805_2012Metric_Pad1.15x1.40mm_HandSolder
CC2, CC3, CC4, CC5, CC6, CC7, CC8, CC9: 100n; C_0402_1005Metric
CPLD: XC95144XL-10CSG144; xilinx_csg144
D1: S1ATR; D_SMA
D2: S1ATR NF; D_SMA
EXTPWR: ext pwr; PinHeader_1x03_P2.54mm_Vertical
FC0, FC1, FC2, FC3, FC4, FC5: 100n; C_0805_2012Metric_Pad1.15x1.40mm_HandSolder
FID1, FID2, FID3: FIDUCIAL; Fiducial_1mm_Dia_2mm_Outer
FLASH0, FLASH1: S29GL064S70DHI010; cypress_lae064_fbga
GPIO: gpio; PinHeader_2x03_P2.54mm_Vertical
MCU: ATSAMD21E18A-AU; TQFP-32_7x7mm_P0.8mm
R1, R6, R7, R8: 10k; R_0805_2012Metric_Pad1.15x1.40mm_HandSolder
R2: 1k; R_0805_2012Metric_Pad1.15x1.40mm_HandSolder
R3: 100R; R_0805_2012Metric_Pad1.15x1.40mm_HandSolder
REG: AP7365-33YG-XX; SOT-89-3
RESET: reset/POR; PinHeader_1x02_P2.54mm_Vertical
ROM1: ROM header; dip32_rom
ROM2, ROM3, ROM4: ROM header; dip32_rom_data_only
RP1, RP2, RP3, RP4: Pack of 8 x isolated 68R resistors; R_Array_Convex_8x0602
SWD: swd; Tag-Connect_TC2030-IDC-FP_2x03_P1.27mm_Vertical
SWD2: swd; PinHeader_2x04_P2.54mm_Vertical
T1: rom_5V; PinHeader_1x01_P2.54mm_Vertical
USB: usb; micro_usb_b_smd_molex
mech_pin1, mech_pin2, mech_pin3, mech_pin4, mech_pin5, mech_pin6, mech_pin7, mech_pin8: dip_rom_single_pin
staple_single1, staple_single2, staple_single3, staple_single4, staple_single5, staple_single6, staple_single7, staple_single8, staple_single9, staple_single10, staple_single11, staple_single12, staple_single13, staple_single14, staple_single15, staple_single16, staple_single17, staple_single18, staple_single19, staple_single20, staple_single21, staple_single22, staple_single23, staple_single24, staple_single25, staple_single26, staple_single27, staple_single28, staple_single29, staple_single30, staple_single31, staple_single32, staple_single33, staple_single34, staple_single35, staple_single36, staple_single37, staple_single38, staple_single39, staple_single40, staple_single41, staple_single42, staple_single43, staple_single44, staple_single45: via_single

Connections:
3V3: BUF.14, C7.1, C10.2, C11.2, C13.2, CC0.1, CC1.1, CC2.1, CC3.1, CC4.1, CC5.1, CC6.1, CC7.1, CC8.1, CC9.1, CPLD.A1, CPLD.A13, CPLD.B3, CPLD.C7, CPLD.D1, CPLD.J13, CPLD.L4, CPLD.L7, CPLD.N1, CPLD.N13, EXTPWR.2, FC0.1, FC1.1, FC2.1, FC3.1, FC4.1, FC5.1, FLASH0.D8, FLASH0.F1, FLASH0.F7, FLASH0.G5, FLASH1.D8, FLASH1.F1, FLASH1.F7, FLASH1.G5, GPIO.2, MCU.9, MCU.30, R1.2, R2.2, R6.2, R7.2, REG.1, SWD.1, SWD2.2
5V: C1.2, C6.2, D1.1, D2.1, EXTPWR.3, REG.3
GND: AEXTGND.1, BUF.1, BUF.5, BUF.7, BUF.10, BUF.12, C1.1, C6.1, C7.2, C10.1, C11.1, C12.1, C13.1, CC0.2, CC1.2, CC2.2, CC3.2, CC4.2, CC5.2, CC6.2, CC7.2, CC8.2, CC9.2, CPLD.B2, CPLD.B8, CPLD.B12, CPLD.C10, CPLD.E11, CPLD.G1, CPLD.G12, CPLD.G13, CPLD.K1, CPLD.M2, CPLD.M5, CPLD.M9, CPLD.M12, EXTPWR.1, FC0.2, FC1.2, FC2.2, FC3.2, FC4.2, FC5.2, FLASH0.E8, FLASH0.H2, FLASH0.H7, FLASH1.E8, FLASH1.H2, FLASH1.H7, GPIO.1, MCU.10, MCU.28, R8.2, REG.2, ROM1.16, ROM2.16, ROM3.16, ROM4.16, SWD.5, SWD2.4, SWD2.6, USB.5, staple_single1.1, staple_single2.1, staple_single3.1, staple_single4.1, staple_single5.1, staple_single6.1, staple_single7.1, staple_single8.1, staple_single9.1, staple_single10.1, staple_single11.1, staple_single12.1, staple_single13.1, staple_single14.1, staple_single15.1, staple_single16.1, staple_single17.1, staple_single18.1, staple_single19.1, staple_single20.1, staple_single21.1, staple_single22.1, staple_single23.1, staple_single24.1, staple_single25.1, staple_single26.1, staple_single27.1, staple_single28.1, staple_single29.1, staple_single30.1, staple_single31.1, staple_single32.1, staple_single33.1, staple_single34.1, staple_single35.1, staple_single36.1, staple_single37.1, staple_single38.1, staple_single39.1, staple_single40.1, staple_single41.1, staple_single42.1, staple_single43.1, staple_single44.1, staple_single45.1
USBDM: MCU.23, USB.2
USBDP: MCU.24, USB.3
VDDCORE: C12.2, MCU.29
VUSB: D2.2, USB.1
arc_POR: R3.2, RESET.2
arc_POR_R: BUF.6, R3.1
arc_RESET: BUF.9, BUF.11, RESET.1
arc_RESET_buffered: BUF.8, MCU.17
cpld_MISO: CPLD.L2, MCU.14
cpld_MOSI: CPLD.M1, MCU.11
cpld_SCK: CPLD.L1, MCU.12
cpld_SS: CPLD.K3, MCU.13
cpld_TCK: CPLD.L10, MCU.6
cpld_TDI: CPLD.L9, MCU.8
cpld_TDO: CPLD.C8, MCU.5
cpld_TMS: CPLD.N10, MCU.7
cpld_clock_from_mcu: CPLD.N2, MCU.27
flash0_DQ0: CPLD.J2, FLASH0.E3
flash0_DQ1: CPLD.F1, FLASH0.H3
flash0_DQ2: CPLD.H1, FLASH0.E4
flash0_DQ3: CPLD.D3, FLASH0.H4
flash0_DQ4: CPLD.N11, FLASH0.H5
flash0_DQ5: CPLD.D5, FLASH0.E5
flash0_DQ6: CPLD.N9, FLASH0.H6
flash0_DQ7: CPLD.L6, FLASH0.E6
flash0_DQ8: CPLD.H2, FLASH0.F3
flash0_DQ9: CPLD.G2, FLASH0.G3
flash0_DQ10: CPLD.M10, FLASH0.F4
flash0_DQ11: CPLD.D4, FLASH0.G4
flash0_DQ12: CPLD.M8, FLASH0.F5
flash0_DQ13: CPLD.N8, FLASH0.G6
flash0_DQ14: CPLD.K7, FLASH0.F6
flash0_DQ15: CPLD.L8, FLASH0.G7
flash1_DQ0: CPLD.F2, FLASH1.E3
flash1_DQ1: CPLD.C1, FLASH1.H3
flash1_DQ2: CPLD.E1, FLASH1.E4
flash1_DQ3: CPLD.B1, FLASH1.H4
flash1_DQ4: CPLD.J11, FLASH1.H5
flash1_DQ5: CPLD.C2, FLASH1.E5
flash1_DQ6: CPLD.K10, FLASH1.H6
flash1_DQ7: CPLD.K8, FLASH1.E6
flash1_DQ8: CPLD.E2, FLASH1.F3
flash1_DQ9: CPLD.D2, FLASH1.G3
flash1_DQ10: CPLD.J10, FLASH1.F4
flash1_DQ11: CPLD.C3, FLASH1.G4
flash1_DQ12: CPLD.L11, FLASH1.F5
flash1_DQ13: CPLD.N12, FLASH1.G6
flash1_DQ14: CPLD.K9, FLASH1.F6
flash1_DQ15: CPLD.M11, FLASH1.G7
flash_A0: CPLD.G4, FLASH0.E2, FLASH1.E2
flash_A1: CPLD.M3, FLASH0.D2, FLASH1.D2
flash_A2: CPLD.M4, FLASH0.C2, FLASH1.C2
flash_A3: CPLD.F3, FLASH0.A2, FLASH1.A2
flash_A4: CPLD.E4, FLASH0.B2, FLASH1.B2
flash_A5: CPLD.N3, FLASH0.D3, FLASH1.D3
flash_A6: CPLD.F4, FLASH0.C3, FLASH1.C3
flash_A7: CPLD.G3, FLASH0.A3, FLASH1.A3
flash_A8: CPLD.N6, FLASH0.B6, FLASH1.B6
flash_A9: CPLD.K5, FLASH0.A6, FLASH1.A6
flash_A10: CPLD.N5, FLASH0.C6, FLASH1.C6
flash_A11: CPLD.K4, FLASH0.D6, FLASH1.D6
flash_A12: CPLD.M6, FLASH0.B7, FLASH1.B7
flash_A13: CPLD.L5, FLASH0.A7, FLASH1.A7
flash_A14: CPLD.K6, FLASH0.C7, FLASH1.C7
flash_A15: CPLD.N7, FLASH0.D7, FLASH1.D7
flash_A16: CPLD.M7, FLASH0.E7, FLASH1.E7
flash_A17: CPLD.L3, FLASH0.B3, FLASH1.B3
flash_A18: CPLD.H3, FLASH0.C4, FLASH1.C4
flash_A19: CPLD.J4, FLASH0.D5, FLASH1.D5
flash_A20: CPLD.J3, FLASH0.D4, FLASH1.D4
flash_A21: CPLD.H4, FLASH0.C5, FLASH1.C5
flash_READY: FLASH0.A4, FLASH1.A4, MCU.16
flash_nCE: CPLD.J1, FLASH0.F2, FLASH1.F2
flash_nOE: CPLD.E3, FLASH0.G2, FLASH1.G2
flash_nRESET: FLASH0.B5, FLASH1.B5, MCU.15
flash_nWE: CPLD.N4, FLASH0.A5, FLASH1.A5
mcu_GPIO0: GPIO.3, MCU.22
mcu_GPIO1: GPIO.4, MCU.21
mcu_GPIO2: GPIO.5, MCU.20
mcu_GPIO3: GPIO.6, MCU.19
mcu_RESET: MCU.26, R1.1, SWD.3, SWD2.5
mcu_SWCLK: MCU.31, R2.1, SWD.4, SWD2.3
mcu_SWDIO: MCU.32, SWD.2, SWD2.1
mcu_debug_RXD: MCU.2, SWD2.8
mcu_debug_TXD: MCU.1, SWD2.7
ndrive_arc_POR: BUF.4, MCU.3, R7.1
ndrive_arc_RESET: BUF.13, MCU.18, R6.1
rom_5V: BUF.2, CPLD.K2, D1.2, R8.1, ROM1.32, T1.1
rom_5V_buffered: BUF.3, MCU.4
rom_A0: CPLD.B13, ROM1.12
rom_A1: CPLD.C12, ROM1.11
rom_A2: CPLD.C11, ROM1.10
rom_A3: CPLD.A11, ROM1.9
rom_A4: CPLD.B11, ROM1.8
rom_A5: CPLD.A8, ROM1.7
rom_A6: CPLD.B6, ROM1.6
rom_A7: CPLD.A3, ROM1.5
rom_A8: CPLD.B4, ROM1.27
rom_A9: CPLD.B5, ROM1.26
rom_A10: CPLD.A6, ROM1.23
rom_A11: CPLD.A5, ROM1.25
rom_A12: CPLD.D6, ROM1.4
rom_A13: CPLD.A2, ROM1.28
rom_A14: CPLD.C5, ROM1.29
rom_A15: CPLD.C4, ROM1.3
rom_A16: AEXT.2, AEXT2.1, CPLD.A9
rom_A16_ext: AEXT.1, ROM1.2
rom_A17: AEXT.4, AEXT2.2, CPLD.B9
rom_A17_ext: AEXT.3, ROM1.30
rom_A18: AEXT.6, AEXT2.3, CPLD.B7
rom_A18_ext: AEXT.5, ROM1.31
rom_A19: A21.1, AEXT.8, AEXT2.4, CPLD.A4
rom_A19_ext: AEXT.7, ROM1.1
rom_D0: CPLD.D11, RP1.4
rom_D0_ext: ROM1.13, RP1.13
rom_D1: CPLD.C13, RP1.6
rom_D1_ext: ROM1.14, RP1.11
rom_D2: CPLD.D12, RP1.8
rom_D2_ext: ROM1.15, RP1.9
rom_D3: CPLD.D8, RP1.7
rom_D3_ext: ROM1.17, RP1.10
rom_D4: CPLD.D7, RP1.5
rom_D4_ext: ROM1.18, RP1.12
rom_D5: CPLD.A12, RP1.3
rom_D5_ext: ROM1.19, RP1.14
rom_D6: CPLD.A10, RP1.2
rom_D6_ext: ROM1.20, RP1.15
rom_D7: CPLD.B10, RP1.1
rom_D7_ext: ROM1.21, RP1.16
rom_D8: CPLD.H12, RP3.1
rom_D8_ext: ROM2.13, RP3.16
rom_D9: CPLD.G10, RP3.7
rom_D9_ext: ROM2.14, RP3.10
rom_D10: CPLD.D9, RP3.2
rom_D10_ext: ROM2.15, RP3.15
rom_D11: CPLD.F13, RP2.5
rom_D11_ext: ROM2.17, RP2.12
rom_D12: CPLD.F12, RP2.4
rom_D12_ext: ROM2.18, RP2.13
rom_D13: CPLD.E13, RP2.3
rom_D13_ext: ROM2.19, RP2.14
rom_D14: CPLD.E12, RP2.2
rom_D14_ext: ROM2.20, RP2.15
rom_D15: CPLD.D13, RP2.1
rom_D15_ext: ROM2.21, RP2.16
rom_D16: CPLD.H10, RP4.1
rom_D16_ext: ROM3.13, RP4.16
rom_D17: CPLD.F11, RP3.5
rom_D17_ext: ROM3.14, RP3.12
rom_D18: CPLD.E10, RP3.4
rom_D18_ext: ROM3.15, RP3.13
rom_D19: CPLD.C9, RP2.8
rom_D19_ext: ROM3.17, RP2.9
rom_D20: CPLD.F10, RP3.6
rom_D20_ext: ROM3.18, RP3.11
rom_D21: CPLD.K13, RP4.4
rom_D21_ext: ROM3.19, RP4.13
rom_D22: CPLD.L13, RP4.6
rom_D22_ext: ROM3.20, RP4.11
rom_D23: CPLD.L12, RP4.7
rom_D23_ext: ROM3.21, RP4.10
rom_D24: CPLD.H13, RP4.2
rom_D24_ext: ROM4.13, RP4.15
rom_D25: CPLD.D10, RP3.3
rom_D25_ext: ROM4.14, RP3.14
rom_D26: CPLD.G11, RP2.6
rom_D26_ext: ROM4.15, RP2.11
rom_D27: CPLD.J12, RP2.7
rom_D27_ext: ROM4.17, RP2.10
rom_D28: CPLD.H11, RP3.8
rom_D28_ext: ROM4.18, RP3.9
rom_D29: CPLD.K12, RP4.3
rom_D29_ext: ROM4.19, RP4.14
rom_D30: CPLD.K11, RP4.5
rom_D30_ext: ROM4.20, RP4.12
rom_D31: CPLD.M13, RP4.8
rom_D31_ext: ROM4.21, RP4.9
rom_nCS: CPLD.C6, ROM1.22
rom_nOE: AEXT.10, CPLD.A7
rom_nOE_ext: AEXT.9, ROM1.24

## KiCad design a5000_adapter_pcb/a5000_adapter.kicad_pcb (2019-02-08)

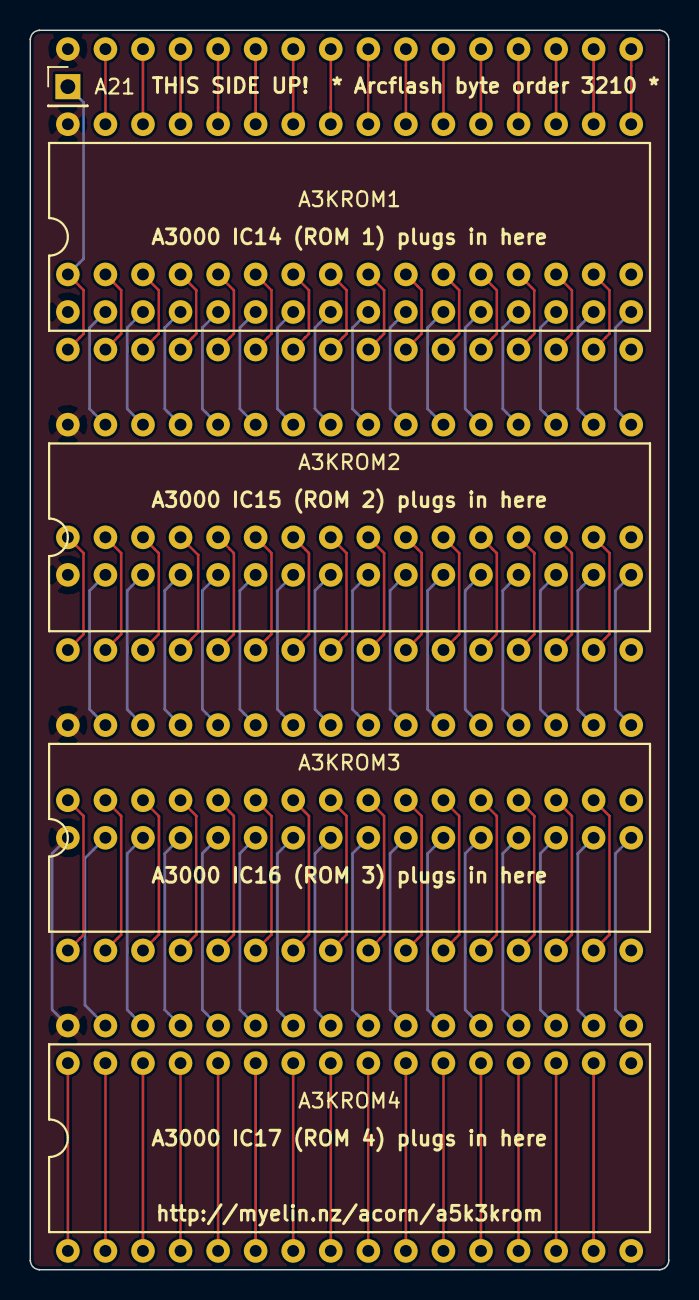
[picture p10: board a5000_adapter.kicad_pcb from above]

Board: 2 copper layers, 43.2 x 83.8 mm, 9 parts (0 on the bottom side), 122 nets.

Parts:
A3KROM1, A3KROM2, A3KROM3, A3KROM4: ROM header; dip32_rom
A5KROM1, A5KROM2, A5KROM3, A5KROM4: ROM header; dip32_rom_bottom
A21: PinHeader_1x01_P2.54mm_Vertical

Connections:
GND: A3KROM1.16, A3KROM2.16, A3KROM3.16, A3KROM4.16, A5KROM1.16, A5KROM2.16, A5KROM3.16, A5KROM4.16
rom1_pin1: A3KROM1.1, A5KROM1.1, A21.1
rom1_pin2: A3KROM1.2, A5KROM1.2
rom1_pin3: A3KROM1.3, A5KROM1.3
rom1_pin4: A3KROM1.4, A5KROM1.4
rom1_pin5: A3KROM1.5, A5KROM1.5
rom1_pin6: A3KROM1.6, A5KROM1.6
rom1_pin7: A3KROM1.7, A5KROM1.7
rom1_pin8: A3KROM1.8, A5KROM1.8
rom1_pin9: A3KROM1.9, A5KROM1.9
rom1_pin10: A3KROM1.10, A5KROM1.10
rom1_pin11: A3KROM1.11, A5KROM1.11
rom1_pin12: A3KROM1.12, A5KROM1.12
rom1_pin13: A3KROM1.13, A5KROM1.13
rom1_pin14: A3KROM1.14, A5KROM1.14
rom1_pin15: A3KROM1.15, A5KROM1.15
rom1_pin17: A3KROM1.17, A5KROM1.17
rom1_pin18: A3KROM1.18, A5KROM1.18
rom1_pin19: A3KROM1.19, A5KROM1.19
rom1_pin20: A3KROM1.20, A5KROM1.20
rom1_pin21: A3KROM1.21, A5KROM1.21
rom1_pin22: A3KROM1.22, A5KROM1.22
rom1_pin23: A3KROM1.23, A5KROM1.23
rom1_pin24: A3KROM1.24, A5KROM1.24
rom1_pin25: A3KROM1.25, A5KROM1.25
rom1_pin26: A3KROM1.26, A5KROM1.26
rom1_pin27: A3KROM1.27, A5KROM1.27
rom1_pin28: A3KROM1.28, A5KROM1.28
rom1_pin29: A3KROM1.29, A5KROM1.29
rom1_pin30: A3KROM1.30, A5KROM1.30
rom1_pin31: A3KROM1.31, A5KROM1.31
rom2_pin1: A3KROM2.1, A5KROM2.1
rom2_pin2: A3KROM2.2, A5KROM2.2
rom2_pin3: A3KROM2.3, A5KROM2.3
rom2_pin4: A3KROM2.4, A5KROM2.4
rom2_pin5: A3KROM2.5, A5KROM2.5
rom2_pin6: A3KROM2.6, A5KROM2.6
rom2_pin7: A3KROM2.7, A5KROM2.7
rom2_pin8: A3KROM2.8, A5KROM2.8
rom2_pin9: A3KROM2.9, A5KROM2.9
rom2_pin10: A3KROM2.10, A5KROM2.10
rom2_pin11: A3KROM2.11, A5KROM2.11
rom2_pin12: A3KROM2.12, A5KROM2.12
rom2_pin13: A3KROM2.13, A5KROM2.13
rom2_pin14: A3KROM2.14, A5KROM2.14
rom2_pin15: A3KROM2.15, A5KROM2.15
rom2_pin17: A3KROM2.17, A5KROM2.17
rom2_pin18: A3KROM2.18, A5KROM2.18
rom2_pin19: A3KROM2.19, A5KROM2.19
rom2_pin20: A3KROM2.20, A5KROM2.20
rom2_pin21: A3KROM2.21, A5KROM2.21
rom2_pin22: A3KROM2.22, A5KROM2.22
rom2_pin23: A3KROM2.23, A5KROM2.23
rom2_pin24: A3KROM2.24, A5KROM2.24
rom2_pin25: A3KROM2.25, A5KROM2.25
rom2_pin26: A3KROM2.26, A5KROM2.26
rom2_pin27: A3KROM2.27, A5KROM2.27
rom2_pin28: A3KROM2.28, A5KROM2.28
rom2_pin29: A3KROM2.29, A5KROM2.29
rom2_pin30: A3KROM2.30, A5KROM2.30
rom2_pin31: A3KROM2.31, A5KROM2.31
rom3_pin1: A3KROM3.1, A5KROM3.1
rom3_pin2: A3KROM3.2, A5KROM3.2
rom3_pin3: A3KROM3.3, A5KROM3.3
rom3_pin4: A3KROM3.4, A5KROM3.4
rom3_pin5: A3KROM3.5, A5KROM3.5
rom3_pin6: A3KROM3.6, A5KROM3.6
rom3_pin7: A3KROM3.7, A5KROM3.7
rom3_pin8: A3KROM3.8, A5KROM3.8
rom3_pin9: A3KROM3.9, A5KROM3.9
rom3_pin10: A3KROM3.10, A5KROM3.10
rom3_pin11: A3KROM3.11, A5KROM3.11
rom3_pin12: A3KROM3.12, A5KROM3.12
rom3_pin13: A3KROM3.13, A5KROM3.13
rom3_pin14: A3KROM3.14, A5KROM3.14
rom3_pin15: A3KROM3.15, A5KROM3.15
rom3_pin17: A3KROM3.17, A5KROM3.17
rom3_pin18: A3KROM3.18, A5KROM3.18
rom3_pin19: A3KROM3.19, A5KROM3.19
rom3_pin20: A3KROM3.20, A5KROM3.20
rom3_pin21: A3KROM3.21, A5KROM3.21
rom3_pin22: A3KROM3.22, A5KROM3.22
rom3_pin23: A3KROM3.23, A5KROM3.23
rom3_pin24: A3KROM3.24, A5KROM3.24
rom3_pin25: A3KROM3.25, A5KROM3.25
rom3_pin26: A3KROM3.26, A5KROM3.26
rom3_pin27: A3KROM3.27, A5KROM3.27
rom3_pin28: A3KROM3.28, A5KROM3.28
rom3_pin29: A3KROM3.29, A5KROM3.29
rom3_pin30: A3KROM3.30, A5KROM3.30
rom3_pin31: A3KROM3.31, A5KROM3.31
rom4_pin1: A3KROM4.1, A5KROM4.1
rom4_pin2: A3KROM4.2, A5KROM4.2
rom4_pin3: A3KROM4.3, A5KROM4.3
rom4_pin4: A3KROM4.4, A5KROM4.4
rom4_pin5: A3KROM4.5, A5KROM4.5
rom4_pin6: A3KROM4.6, A5KROM4.6
rom4_pin7: A3KROM4.7, A5KROM4.7
rom4_pin8: A3KROM4.8, A5KROM4.8
rom4_pin9: A3KROM4.9, A5KROM4.9
rom4_pin10: A3KROM4.10, A5KROM4.10
rom4_pin11: A3KROM4.11, A5KROM4.11
rom4_pin12: A3KROM4.12, A5KROM4.12
rom4_pin13: A3KROM4.13, A5KROM4.13
rom4_pin14: A3KROM4.14, A5KROM4.14
rom4_pin15: A3KROM4.15, A5KROM4.15
rom4_pin17: A3KROM4.17, A5KROM4.17
rom4_pin18: A3KROM4.18, A5KROM4.18
rom4_pin19: A3KROM4.19, A5KROM4.19
rom4_pin20: A3KROM4.20, A5KROM4.20
rom4_pin21: A3KROM4.21, A5KROM4.21
rom4_pin22: A3KROM4.22, A5KROM4.22
rom4_pin23: A3KROM4.23, A5KROM4.23
rom4_pin24: A3KROM4.24, A5KROM4.24
rom4_pin25: A3KROM4.25, A5KROM4.25
rom4_pin26: A3KROM4.26, A5KROM4.26
rom4_pin27: A3KROM4.27, A5KROM4.27
rom4_pin28: A3KROM4.28, A5KROM4.28
rom4_pin29: A3KROM4.29, A5KROM4.29
rom4_pin30: A3KROM4.30, A5KROM4.30
rom4_pin31: A3KROM4.31, A5KROM4.31
rom_5V: A3KROM1.32, A3KROM2.32, A3KROM3.32, A3KROM4.32, A5KROM1.32, A5KROM2.32, A5KROM3.32, A5KROM4.32

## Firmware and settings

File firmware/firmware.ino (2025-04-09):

// Copyright 2018 Google LLC
//
// Licensed under the Apache License, Version 2.0 (the "License");
// you may not use this file except in compliance with the License.
// You may obtain a copy of the License at
//
//     http://www.apache.org/licenses/LICENSE-2.0
//
// Unless required by applicable law or agreed to in writing, software
// distributed under the License is distributed on an "AS IS" BASIS,
// WITHOUT WARRANTIES OR CONDITIONS OF ANY KIND, either express or implied.
// See the License for the specific language governing permissions and
// limitations under the License.

#include <SPI.h>

// Autogenerated version string
#include "version.h"

// For pinPeripheral(), so we can change PINMUX
#include "wiring_private.h"

// For libxsvf, so we can program the CPLD
#include "libxsvf.h"

// For comms with the host processor
#include "host_mcu_comms.h"

// This code is for the ATSAMD21E18A onboard an a3000_rom_emulator PCB.
// Functions provided:
// - USB serial interface for all control
// - USB SVF+JTAG interface to program the CPLD
// - CPLD clock generation (48MHz)

// Pinout:

// Pin assignments from the Adafruit Circuit Playground Express (ATSAMD21G18A)
// are used here.  Be careful mapping these to actual pins, because the G18A and
// our E18A have different pinouts.

// Mapping: A(x) = D(x+14), e.g. A0 = D14 and A10 = D24

// CPLD JTAG port

// PA04 - D24 / A10
#define TDO_PIN 24
// PA06 - D16 / A2
#define TMS_PIN 16
// PA05 - D15 / A1
#define TCK_PIN 15
// PA07 - D17 / A3
#define TDI_PIN 17

// CPLD comms

// PA08 / SERCOM2.0 (SERCOM-ALT) - D35 - cpld_MOSI
#define CPLD_MOSI_PIN 35
// PA09 / SERCOM2.1 (SERCOM-ALT) - D23 - cpld_SCK
#define CPLD_SCK_PIN 23
// PA10 / SERCOM2.2 (SERCOM-ALT) - D34 - cpld_SS
#define CPLD_SS_PIN 34
#define CPLD_SS_PORT (PORT->Group[0])
#define CPLD_SS_PORT_BIT 10
#define CPLD_SS_SET() do { CPLD_SS_PORT.OUTSET.reg = 1 << CPLD_SS_PORT_BIT; } while (0)
#define CPLD_SS_CLEAR() do { CPLD_SS_PORT.OUTCLR.reg = 1 << CPLD_SS_PORT_BIT; } while (0)
// #define CPLD_SS_CLEAR() digitalWrite(CPLD_SS_PIN, LOW)
// #define CPLD_SS_SET() digitalWrite(CPLD_SS_PIN, HIGH)
// PA11 / SERCOM2.3 (SERCOM-ALT) - D22 - cpld_MISO
#define CPLD_MISO_PIN 22

// PA14 - D5 - flash_nRESET (pull up)
#define FLASH_NRESET_PIN 5
// PA15 - D7 - flash_nREADY (pull up)
#define FLASH_NREADY_PIN 7

// PA28 - D4 - cpld_clock_from_mcu (clock output)
#define CPLD_CLOCK_FROM_MCU_PIN 4

// PA16 (MCU pin 17) - 3v3 version of /RESET
// This is shown as pin 11 in the comment at the top of circuitplay/variant.cpp,
// but is pin 30 in g_APinDescription.  TODO fix this in arduino
#define arc_RESET_buffered_PIN 30
// PA17 (MCU pin 18) - pull low to drive /RESET
// Unfortunately this is also the LED pin, so the bootloader causes interesting reset patterns.
#define ndrive_arc_RESET_PIN 13
// PA03 (MCU pin 4) - 3v3 version of rom_5V, NC on v1 board
#define rom_5V_buffered_PIN rom_5V_needs_arduino_pin_assignment_TODO
// PA02 (MCU pin 3) - pull low to drive /POR (hold low for a while as it has to discharge 10u via 133R), NC on v1 board
#define ndrive_arc_POR_PIN 14


// Uncomment this to show every byte sent and received over SPI
// #define SHOW_ALL_SPI_TRANSFERS

// Uncomment this to show all flash reads and writes
// #define SHOW_ALL_FLASH_ACCESS

// Disable USB serial commands (CPLD programming etc) by commenting this out:
#define ENABLE_USB_SERIAL

// Uncomment this to disable programming flash (for performance testing)
// #define DEBUG_DONT_PROGRAM_FLASH

// Uncomment this to fake out fetching data from USB (for performance testing)
// #define DEBUG_DONT_GET_USB_DATA


// We have the S29GL064S70DHI010 (S29GL064S 70-ns D-LAE064-BGA-pkg H-halogen/lead-free I-industrial 01-uniform sector 0-tray)
// 2 x 64 (4Mwordx16) megabit flash chips, so addresses are 22 bits long
#define CHIP_SIZE (4 * 1048576L)
// Sectors are 32k word / 64kB long
#define SECTOR_SIZE (32768L)
#define SECTOR_MASK ((CHIP_SIZE * 4 - 1) & ~(SECTOR_SIZE - 1))


// libxsvf (xsvftool-arduino) entry point
extern void arduino_play_svf(int tms_pin, int tdi_pin, int tdo_pin, int tck_pin, int trst_pin);

// SPI on SERCOM2 to talk to the CPLD at 24MHz
SPIClass cpld_spi(&sercom2, CPLD_MISO_PIN, CPLD_SCK_PIN, CPLD_MOSI_PIN, SPI_PAD_0_SCK_1, SERCOM_RX_PAD_3);

// Alternate function: UART to talk to host
Uart cpld_uart(&sercom2, CPLD_MISO_PIN, CPLD_MOSI_PIN, SERCOM_RX_PAD_3, UART_TX_PAD_0);
// to enable: cpld_uart.begin(); then same pinPeripheral calls as for SPI (because we're using the same sercom pins/pads, just a different function.)

enum class SpiPortState {
  NOTHING_SELECTED,
  SPI_SELECTED,
  UART_SELECTED,
};
SpiPortState spi_port_state = SpiPortState::NOTHING_SELECTED;

#define WAIT_FOR_SERIAL_OR_BREAK() \
  while (!Serial.available()) { \
    if (check_disconnect()) break; \
  }

// Set MOSI/SCK/MISO/SS pins up for SPI comms with CPLD
void select_spi() {
  if (spi_port_state == SpiPortState::SPI_SELECTED) return;
  spi_port_state = SpiPortState::SPI_SELECTED;
  if (Serial.dtr()) Serial.println("select spi");
  sercom2.disableSPI();  // disable SERCOM so we can write registers
  cpld_spi.begin();
  pinPeripheral(CPLD_MOSI_PIN, PIO_SERCOM_ALT);
  pinPeripheral(CPLD_SCK_PIN, PIO_SERCOM_ALT);
  pinPeripheral(CPLD_MISO_PIN, PIO_SERCOM_ALT);
  cpld_spi.beginTransaction(SPISettings(12000000L, MSBFIRST, SPI_MODE0));
}

// Set MOSI/MISO pins up for UART comms with host machine (forwarded by CPLD)
void select_uart() {
  if (spi_port_state == SpiPortState::UART_SELECTED) return;
  spi_port_state = SpiPortState::UART_SELECTED;
  if (Serial.dtr()) Serial.println("select uart");
  sercom2.disableSPI();  // disable SERCOM so we can write registers
  cpld_uart.begin(host_mcu_comms::kUartBaud);
  pinPeripheral(CPLD_MOSI_PIN, PIO_SERCOM_ALT);
  pinPeripheral(CPLD_MISO_PIN, PIO_SERCOM_ALT);
  // disable all interrupts that begin() enables
  SERCOM2->USART.INTENCLR.reg = SERCOM_USART_INTENSET_DRE |
                                SERCOM_USART_INTENSET_RXC |
                                SERCOM_USART_INTENSET_ERROR;

}

// Send/receive a byte over SPI, optionally dumping details to the serial port
uint8_t spi_transfer(uint8_t b) {
  uint8_t r = cpld_spi.transfer(b);
#ifdef SHOW_ALL_SPI_TRANSFERS
  Serial.print("[");
  Serial.print(b, HEX);
  Serial.print(" -> ");
  Serial.print(r, HEX);
  Serial.print("]");
#endif
  return r;
}

// Write a 32-bit word to the flash chips
void flash_write(uint32_t A, uint32_t D) {
  // Write a 32-bit word to the flash, leaving allowing_arm_access == 0
  CPLD_SS_CLEAR();
  spi_transfer((uint8_t)(0x00 | ((A & 0x3f0000L) >> 16L)));  // allowing_arm_access, rnw, A[21:16]
  spi_transfer((uint8_t)((A & 0xff00L) >> 8L));  // A[15:8]
  spi_transfer((uint8_t)(A & 0xffL));  // A[7:0]
  spi_transfer((uint8_t)((D & 0xff000000L) >> 24L));  // D[31:24]
  spi_transfer((uint8_t)((D & 0xff0000L) >> 16L));  // D[23:16]
  spi_transfer((uint8_t)((D & 0xff00L) >> 8L));  // D[15:8]
  spi_transfer((uint8_t)(D & 0xffL));  // D[7:0]
  spi_transfer(0);
  CPLD_SS_SET();
#ifdef SHOW_ALL_FLASH_ACCESS
  Serial.print("Flash write *0x");
  Serial.print(A, HEX);
  Serial.print(" = ");
  Serial.println(D, HEX);
#endif
}

// Write a 16-bit word to the same address on both flash chips
void flash_write_both(uint32_t A, uint16_t D) {
  uint32_t D32 = D;
  flash_write(A, D32 | (D32 << 16));
}

// Read a 32-bit word from the flash chips
uint32_t flash_read(uint32_t A) {
  // Read a 32-bit word from the flash, leaving allowing_arm_access == 0
  CPLD_SS_CLEAR();
  spi_transfer((uint8_t)(0x40 | ((A & 0x3f0000) >> 16)));  // allowing_arm_access, rnw, A[21:16]
  spi_transfer((uint8_t)((A & 0xff00) >> 8));  // A[15:8]
  spi_transfer((uint8_t)(A & 0xff));  // A[7:0]
  spi_transfer(0);
  uint32_t D = ((uint32_t)spi_transfer(0)) << 24;  // D[31:24]
  D |= ((uint32_t)spi_transfer(0)) << 16;  // D[23:16]
  D |= ((uint32_t)spi_transfer(0)) << 8;  // D[15:8]
  D |= ((uint32_t)spi_transfer(0));  // D[7:0]
  CPLD_SS_SET();
#ifdef SHOW_ALL_FLASH_ACCESS
  Serial.print("Flash read *0x");
  Serial.print(A, HEX);
  Serial.print(" == ");
  Serial.println(D, HEX);
#endif
  return D;
}

// 7 bits: allowing_arm_access=1, disable_serial_port (0x40), use_la21 (0x20), use_la20 (0x10), bank:4
#define ALLOWING_ARM_ACCESS 0x80
#define DISABLE_SERIAL_PORT 0x40
// Select bank size with use_la21 (>2M) and use_la20 (>1M)
#define BANK_4M   0x30
#define BANK_2M   0x10
#define BANK_1M   0x00
// Send zero to select 1M bank zero, for the graphical menu bootloader.
#define SELECT_BOOTLOADER 0

static uint8_t flash_bank_select_command =
    SELECT_BOOTLOADER;  // initial for Arc/RPC: bootloader bank, 1M
//  0 | BANK_2M;  // A310 with RO3 and no bootloader
//  0 | BANK_4M;  // Risc PC @ 0
//  4 | BANK_4M;  // Risc PC @ 4M
//  8 | BANK_4M;  // Risc PC @ 8M
//  12 | BANK_4M;  // Risc PC @ 12M

// Tell the CPLD to return control of the flash to the host machine
void flash_unlock() {
  select_spi();

  // Reset allowing_arm_access to 1 in the CPLD, and update the bank
  // select settings if they have changed.
  CPLD_SS_CLEAR();
  spi_transfer(ALLOWING_ARM_ACCESS | flash_bank_select_command);
  CPLD_SS_SET();
}

// Select a particular flash bank.
void select_flash_bank(uint8_t bank_select_command) {
  flash_bank_select_command = bank_select_command;
  if (Serial.dtr()) {
    Serial.print("Send flash bank select command 0x");
    Serial.println(flash_bank_select_command, HEX);
  }
  flash_unlock();
}

// Pulse NRESET on the flash chips
void flash_reset() {
  pinMode(FLASH_NRESET_PIN, OUTPUT);
  digitalWrite(FLASH_NRESET_PIN, LOW);
  digitalWrite(FLASH_NRESET_PIN, HIGH);
  pinMode(FLASH_NRESET_PIN, INPUT_PULLUP);
}

// System startup
void setup() {

  // TODO detect v1 or v2 board by attempting to pull rom_5V_buffered up/down.
  // On a v1 board this is NC so we'll be able to pull it.  On v2 it'll remain
  // driven.
  // pinMode(rom_5V_buffered_PIN, INPUT_PULLDOWN);  // TODO figure out how to access PA03
  pinMode(arc_RESET_buffered_PIN, INPUT_PULLUP);

  // On v2 boards we want to leave RESET and POR undriven by default
  pinMode(ndrive_arc_RESET_PIN, OUTPUT);
  digitalWrite(ndrive_arc_RESET_PIN, HIGH);
  pinMode(ndrive_arc_POR_PIN, OUTPUT);
  digitalWrite(ndrive_arc_POR_PIN, HIGH);

  // Set up fast SPI comms on SERCOM2 with CPLD
  pinMode(CPLD_SS_PIN, OUTPUT);
  CPLD_SS_SET();
  select_spi();

  // Select configured flash_bank
  flash_unlock();

  // I made a poor pin choice in the v1 board, putting cpld_clock_from_mcu on
  // PA28, which is GCLK_IO[0].  It looks like only GCLK0 can drive GCLK_MAIN,
  // so to change the clock frequency output on PA28, we need to slow down the
  // CPU.

  // DIV=2 gives 24MHz, but breaks USB
  // DIV=0 gives 48MHz
  GCLK->GENDIV.reg = GCLK_GENDIV_ID(0) | GCLK_GENDIV_DIV(0);
  while (GCLK->STATUS.reg & GCLK_STATUS_SYNCBUSY);

  // Update with same settings as in Arduino SAMD startup.c, but also
  // GCLK_GENCTRL_OE, to output the clock on GCLK_IO[0].  (Also, is there a
  // way to read the current settings for a GCLK, so I can just set the OE bit
  // without having to repeat the config?)
  GCLK->GENCTRL.reg = GCLK_GENCTRL_ID(0) |
                      GCLK_GENCTRL_SRC_DFLL48M |
                      GCLK_GENCTRL_OE |
                      GCLK_GENCTRL_IDC |
                      GCLK_GENCTRL_GENEN;
  while (GCLK->STATUS.reg & GCLK_STATUS_SYNCBUSY);

  // enable GCLK_IO[0] on PA28 (cpld_clock_from_mcu)
  pinPeripheral(CPLD_CLOCK_FROM_MCU_PIN, PIO_AC_CLK);

  // Set pin directions for CPLD JTAG.
  pinMode(TDO_PIN, INPUT);
  pinMode(TDI_PIN, OUTPUT);
        digitalWrite(TDI_PIN, HIGH);
  pinMode(TMS_PIN, OUTPUT);
        digitalWrite(TMS_PIN, HIGH);
  pinMode(TCK_PIN, OUTPUT);
        digitalWrite(TCK_PIN, LOW);

  // Set up pullups for flash pins
  flash_reset();
  pinMode(FLASH_NREADY_PIN, INPUT_PULLUP);

  // Set up USB serial port
  Serial.begin(9600);

  select_uart();
}

// Read a byte from the USB serial port
uint8_t serial_get_uint8() {
  while (!Serial.available());
  return (uint8_t)Serial.read();
}

// Read a little-endian uint32 from the USB serial port
uint32_t serial_get_uint32() {
  uint32_t v = (uint32_t)serial_get_uint8();
  v |= (uint32_t)serial_get_uint8() << 8L;
  v |= (uint32_t)serial_get_uint8() << 16L;
  v |= (uint32_t)serial_get_uint8() << 24L;
  return v;
}

// Write a little-endian uint32 to the USB serial port
void serial_put_uint32(uint32_t v) {
  Serial.write((uint8_t)(v & 0xFF));
  Serial.write((uint8_t)((v & 0xFF00) >> 8));
  Serial.write((uint8_t)((v & 0xFF0000) >> 16));
  Serial.write((uint8_t)((v & 0xFF000000) >> 24));
}

// USB chunks: read 16kB at a time
#define CHUNK_SIZE (16384 / 4)
#define BUF_SIZE (CHUNK_SIZE + 1)
// Program 512 bytes (128 words) at a time
#define PROGRAM_BLOCK_SIZE 128

// TODO move all these vars into the programming code -- we have more RAM in this chip than the atmega32u4 this was originally written for
static uint32_t read_buf[BUF_SIZE];
#define BUF_SIZE_U8 (BUF_SIZE * 4)
static uint8_t *read_buf_u8 = (uint8_t *)read_buf;

// count of chars read into read_buf
static int buf_pos = 0;

// flash chip size
uint32_t chip_end = 0L;

// for range programming state
uint32_t range_start = 0L, range_end = 0L; // range left to program
int range_chunk_size = 0; // how many bytes to expect in the buffer
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
void loop() {

  // monitor RESET line for double clicks (which tells us to reset/POR into the bootloader)
  int current_reset_value = digitalRead(arc_RESET_buffered_PIN);
  if (current_reset_value != stable_reset_value) {
    long now = millis();
    if (now - stable_reset_transition_at > RESET_DEBOUNCE_DELAY) {
      stable_reset_value = current_reset_value;
      stable_reset_transition_at = now;
      if (!stable_reset_value) {
        Serial.println("RESET active");
      } else {
        Serial.println("RESET inactive");
      }
      reset_changed();
    }
  }

  if (double_click_detected) {
    Serial.println("Double click detected!  Selecting bootloader.");
    double_click_detected = false;
    select_flash_bank(SELECT_BOOTLOADER);
    // And do a hard reset
    power_on_reset();
  }

  // Switch to serial mode if we're in SPI mode.  This will do nothing
  // if we're already in serial mode.
  select_uart();

  if (sercom2.availableDataUART()) {
    if (sercom2.isFrameErrorUART()) {
      // Ignore char with frame error
      sercom2.clearFrameErrorUART();
      uint8_t c = sercom2.readDataUART();
      if (Serial.dtr() && c != 0 && c != 0xFF) {
        Serial.print("frame error: ");
        Serial.println(c, HEX);
        // TODO this should probably abort a packet in progress?
      }
    } else {
      process_char_received_from_host_serial_channel(sercom2.readDataUART());
    }
  }

#ifdef ENABLE_USB_SERIAL
  static uint8_t serial_active = 0;
  static unsigned long serial_active_when = 0;
  if (!Serial.dtr()) {
    if (serial_active) {
      serial_active = 0;
    }
  } else if (!serial_active) {
    // USB serial connection is active
    serial_active_when = millis();
    serial_active = 1;
  } else if (serial_active == 1 && millis() - serial_active_when > 10) {
    // Serial port should have settled by now
    Serial.print("Arcflash ");
    Serial.print(ARCFLASH_BUILD_VERSION);
    Serial.print("; CPU clock: ");
    Serial.println(SystemCoreClock);
    Serial.println("OK");
    serial_active = 2;
  } else if (serial_active == 2) {
    // Serial port is actually open.
  }

  if (Serial.available()) {
    int c = Serial.read();
    switch (c) {
      case 'B': {
        // benchmark
        chip_end = chip_size();
        chip_end = 512 * 1024;
        Serial.print("Reading ");
        Serial.print(chip_end);
        Serial.println(" bytes from flash...");
        for (uint32_t addr = 0; addr < chip_end / 4; ++addr) {
          (void)flash_read(addr);
        }
        Serial.println("Done.");
        reset();
        break;
      }
      case 'C': {
        // program CPLD
        Serial.println("SEND SVF");
        arduino_play_svf(TMS_PIN, TDI_PIN, TDO_PIN, TCK_PIN, -1);
        Serial.println("SVF DONE");
        reset();
        break;
      }
      case 'I': {
        Serial.println("IDENTIFY FLASH");
        select_spi();

        flash_write_both(0x55, 0x0098L);  // Enter CFI mode

        Serial.print("Device size: 2^");
        Serial.print(flash_read(0x27) & 0xffff);
        Serial.println(" bytes");

        for (uint32_t cfi_addr = 0x10; cfi_addr <= 0x50; ++cfi_addr) {
          Serial.print("CFI 0x");
          Serial.print(cfi_addr, HEX);
          Serial.print(": ");
          Serial.println(flash_read(cfi_addr), HEX);
        }

        flash_write_both(0x00, 0xf0);  // Exit CFI mode
        flash_unlock();  // Allow host access again

        chip_end = chip_size();
        Serial.print("Size = ");
        Serial.println(chip_end);

        Serial.println("OK");
        reset();
        break;
      }
      case 'K': {
        // Continuity check, section 10.16 in the datasheet
        Serial.println("CONTINUITY CHECK");
        select_spi();

        flash_write_both(0x555, 0x0071);
        flash_write_both(0x555, 0x0070);
        uint32_t status = flash_read(0);
        Serial.println(status, HEX);  // expect bit zero = 0
        if (status & 1) {
          Serial.println("FAIL - FLASH0 continuity check bit is stuck.");
        }
        if (status & 0x10000) {
          Serial.println("FAIL - FLASH1 continuity check bit is stuck.");
        }
        flash_write_both(0x2aaa55, 0xff00);
        flash_write_both(0x1555aa, 0x00ff);
        flash_write_both(0x555, 0x0070);
        status = flash_read(0);
        Serial.println(status, HEX);  // expect bit zero = 1
        if (!(status & 1)) {
          Serial.println("FAIL - FLASH0 continuity test did not pass.");
        }
        if (!(status & 0x10000)) {
          Serial.println("FAIL - FLASH1 continuity test did not pass.");
        }
        flash_unlock();
        reset();
        break;
      }
      case 'P': {
        // P <start_addr> <end_addr>\n
        chip_end = chip_size();
        WAIT_FOR_SERIAL_OR_BREAK();
        switch (Serial.read()) {
          case '\n': {
            // Program whole chip.
            Serial.print("Program whole chip; chip size = ");
            Serial.println(chip_end);
            program_range(0, chip_end / 4);
            break;
          }
          case ' ': {
            Serial.println("Program range");
            // Program range.
            uint32_t start_addr = 0, end_addr = 0;
            if (!read_uint32_from_serial(start_addr)) break;
            Serial.println(start_addr);
            // Don't need to wait for serial after read_uint32_from_serial.
            if (Serial.read() != ' ') break;
            if (!read_uint32_from_serial(end_addr)) break;
            Serial.println(end_addr);
            // Don't need to wait for serial after read_uint32_from_serial.
            if (Serial.read() != '\n') break;
            Serial.print("Program from ");
            Serial.print(start_addr);
            Serial.print(" to ");
            Serial.print(end_addr);
            Serial.print("; chip size = ");
            Serial.println(chip_end);
            program_range(start_addr / 4, end_addr / 4);
            break;
          }
          default:
            break;
        }
        reset();
        break;
      }
      case 'O': {
        power_on_reset();
        break;
      }
      case 'R': {
        chip_end = chip_size();
        Serial.print("Read whole chip.  Size = ");
        Serial.println(chip_end);
        Serial.print("DATA:");
        // chip_end == number of bytes in a single chip, i.e. 2 * number of words
        for (uint32_t chunk_start = 0; chunk_start < chip_end / 4; chunk_start += CHUNK_SIZE / 4) {
          // Read 16kB from flash
          for (uint32_t offset = 0; offset < CHUNK_SIZE/4; ++offset) {
            read_buf[offset] = flash_read(chunk_start + offset);
          }
          // fail gracefully on disconnect
          uint32_t bytes_to_write = CHUNK_SIZE, bytes_written = 0;
          do {
            if (check_disconnect()) return;
            bytes_written += Serial.write(((char *)read_buf) + bytes_written, bytes_to_write);
          } while (bytes_written < bytes_to_write);
        }
        flash_unlock();
        reset();
        break;
      }
      case 'S': {
        Serial.println("S");
        select_uart();
        Serial.println("send *");
        sercom2.writeDataUART(42);
        while (!sercom2.isDataRegisterEmptyUART());
        Serial.println("done");
        break;
      }
      case 'X': {
        // restart
        Serial.println("Reset to bootloader");
        select_flash_bank(0);
        break;
      }
      case 'Y': {
        Serial.println("Enter bank start (MB, 0-9), then bank size (1, 2, 4).");
        while (!Serial.available()) {
          if (check_disconnect()) break;
        }
        uint8_t bank_c = Serial.read();
        while (!Serial.available()) {
          if (check_disconnect()) break;
        }
        uint8_t size_c = Serial.read();

        uint8_t bank = bank_c - '0';
        if (bank > 9) bank = 0;

        switch (size_c) {
        case '2': bank |= BANK_2M; break;
        case '4': bank |= BANK_4M; break;
        default: bank |= BANK_1M;
        }

        select_flash_bank(bank);
        reset();
        break;
      }
      case 'Z': {
        // USB test
        Serial.println("USB TEST");
        bool fail = false;
        for (uint32_t i = 0; i < 128 * 1024L; ++i) {
          // Serial.println(i);
          unsigned long now = millis();
          while (!Serial.available()) {
            if (millis() - now > 1000) {
              Serial.println("Failing b/c no input for 1000 ms");
              fail = true;
              break;
            }
          }
          if (fail) {
            Serial.println("fail");
            break;
          }
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

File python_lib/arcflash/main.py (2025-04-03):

# Copyright 2025 Google LLC
#
# Licensed under the Apache License, Version 2.0 (the "License");
# you may not use this file except in compliance with the License.
# You may obtain a copy of the License at
#
#     http://www.apache.org/licenses/LICENSE-2.0
#
# Unless required by applicable law or agreed to in writing, software
# distributed under the License is distributed on an "AS IS" BASIS,
# WITHOUT WARRANTIES OR CONDITIONS OF ANY KIND, either express or implied.
# See the License for the specific language governing permissions and
# limitations under the License.

import argparse
import importlib.resources
import os
import sys
import re

import arcflash._bossa
import arcflash.config
import arcflash.program_cpld
import arcflash.rombuild
import arcflash.uploader

def main():
    parser = argparse.ArgumentParser(description='Arcflash command line tool')
    subparsers = parser.add_subparsers(dest='command', help='Available commands')

    # 'arcflash config'
    config_parser = subparsers.add_parser('config', help='Create or add to arcflash.toml configuration file')
    config_parser.add_argument('roms', nargs='+', help='Path to ROM image files to add')

    # 'arcflash program-boot-menu'
    subparsers.add_parser('program-boot-menu', help='Program boot menu on a connected Arcflash board')

    # 'arcflash program-cpld'
    program_cpld_parser = subparsers.add_parser('program-cpld', help='Program CPLD on a connected Arcflash board')
    program_cpld_parser.add_argument('filename', nargs='?', help='Path to the SVF file to upload')

    # 'arcflash program-mcu'
    program_mcu_parser = subparsers.add_parser('program-mcu', help='Program microcontroller firmware on a connected Arcflash board')
    program_mcu_parser.add_argument('filename', nargs='?', help='Path to the .bin file to upload')

    # 'arcflash upload'
    upload_parser = subparsers.add_parser('upload', help='Upload a flash image file to a connected Arcflash board')
    upload_parser.add_argument('filename', help='Path to the flash image file to upload')
    # TODO ' (optionally path@offset+length)'

    args = parser.parse_args()

    if args.command == 'config':
        arcflash.config.update_config(roms=args.roms)
        return 0

    if args.command == 'program-boot-menu':
        # Program boot menu into the start of flash.
        bootloader_binary = arcflash.rombuild.get_bootloader_binary()
        arcflash.uploader.upload("boot menu", bootloader_binary)
        return 0

    if args.command == 'program-cpld':
        # Program CPLD.
        if args.filename:
            return arcflash.program_cpld.program(args.filename)
        ref = importlib.resources.files('arcflash') / 'cpld.svf'
        with importlib.resources.as_file(ref) as path:
            return arcflash.program_cpld.program(str(path))

    if args.command == 'program-mcu':
        # Program microcontroller firmware.
        port = arcflash.port.guess_port()
        if not port:
            print("Could not guess serial port")
            return 1
        if args.filename:
            r = arcflash._bossa.program(port, args.filename)
        else:
            ref = importlib.resources.files('arcflash') / 'firmware.bin'
            with importlib.resources.as_file(ref) as path:
                r = arcflash._bossa.program(port, str(path))
        if r:
            return 1

        print("\n"
            "Done!  If you get a popup about ARCBOOT not being ejected properly, ignore it;\n"
            "it's a side effect of the UF2 bootloader resetting after the download.")
        return 0

    if args.command == 'upload':
        # Upload something into flash.

        if os.path.isdir(args.filename):
            # It's a new-style directory containing an arcflash.toml.
            image = arcflash.rombuild.build_rom_from_dir(args.filename)
            arcflash.uploader.upload(args.filename, image)
            return 0

        # Read image to upload.
        m = re.fullmatch(r"(.*?)(?:\@(\d+)(?:\+(\d+))?)?", args.filename)
        filename, offset, length = m.groups()
        offset = int(offset) if offset else None
        length = int(length) if length else None
        if not os.path.exists(filename):
            print(f"Flash image file {filename} not found")
            return 1

        with open(filename, 'rb') as f:
            image = f.read()

        arcflash.uploader.upload(filename, image, offset, length)
        return 0

    parser.print_help()
    return 1

if __name__ == '__main__':
    sys.exit(main())

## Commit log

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2017-10-31 Fixed up drill file building -- it doesn't appear to work until the plotter has been closed
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2017-11-08 atsamd21_usb_host: Breakout board with an ATSAMD21 chip and a USB-A socket (and a micro USB socket)
2017-11-14 bbc_power: power board to run a BBC B or Master without the usual PSU
2017-11-15 econet_hub: Socket box + clock + termination for a small Econet network
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2018-06-05 Added instruction for how to copy the system Python executable into kicad.app
2018-06-06 ARM fixes
2018-11-22 a3000_rom_emulator: draft daisychain routing of the flash chips done
    [a3000_rom_emulator.kicad_pcb]
2018-11-23 In-progress A3000 ROM emulator board
    [a3000_rom_emulator.kicad_pcb]
2018-11-24 Fixed hole sizes in sockets, and removed flash2-5
    [a3000_rom_emulator.kicad_pcb]
2018-12-01 a3000_rom_emulator: all components placed, ready to route the big CPLD I think
    [a3000_rom_emulator.kicad_pcb]
2018-12-04 CPLD partially routed
    [a3000_rom_emulator.kicad_pcb]
2018-12-06 Fully routed PCB (still needs tidying) and basic Verilog for a3000_rom_emulator
    [a3000_rom_emulator.kicad_pcb]
2018-12-07 Tidy up some traces
    [a3000_rom_emulator.kicad_pcb]
2018-12-07 More tidying, plus added 30 ground staples, and removed some spurious lines from constraints.ucf
    [a3000_rom_emulator.kicad_pcb]
2018-12-07 Silkscreen, some tracks
    [a3000_rom_emulator.kicad_pcb]
2018-12-11 Added AEXT2 connector to bring A18:21 out at a second location that is more convenient on A310/A3000
    [a3000_rom_emulator.kicad_pcb]
2018-12-11 Added some more staples
    [a3000_rom_emulator.kicad_pcb]
2018-12-13 Updated URL
    [a3000_rom_emulator.kicad_pcb]
2018-12-17 Added pullup on A21, for predictable results when it's not wired to the motherboard
    [a3000_rom_emulator.kicad_pcb]
2018-12-17 Added some more via staples
    [a3000_rom_emulator.kicad_pcb]
2018-12-17 tidied some silkscreen and regenerated renders
    [a3000_rom_emulator.kicad_pcb]
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2018-12-19 Updated RAM connector per cmorley's advice on Stardot: moved the left block of 20 pins 25 mils right
2018-12-21 arcflash ready for fab, I think
    [a3000_rom_emulator.kicad_pcb]
2018-12-21 Added 3 fiducials
    [a3000_rom_emulator.kicad_pcb]
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2018-12-28 Generated position files for v1, including fiducials (which needed to be changed from virtual to smd placement type to show up in the .pos files)
    [a3000_rom_emulator.kicad_pcb]
2018-12-28 Regenerated component file including all parts (some were missing 'insert')
2018-12-28 Set smd attribute on parts that weren't showing up in the pos files
    [a3000_rom_emulator.kicad_pcb]
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2019-01-05 Benchmarking and debugging, and made chip_size() return total bytes on the board rather than for one chip
2019-01-07 A5000 adapter board for Arcflash project
    [a5000_adapter.kicad_pcb]
2019-01-07 Wired up adapter, and brought out A21 for easy connection to arcflash board
    [a5000_adapter.kicad_pcb]
2019-01-08 start of assembly routines -- simple one just to reset system
2019-01-08 Support switching flash banks over SPI, and set flash bank==2 (arbitrary bank) on startup, to test that it's possible to switch banks before the system comes to life. Also the start of a byte-wide co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
2019-01-11 Progress: the program now links, and appears to run OK in Arculator. One big glitch was that I didn't have .rodata in the text segment, and it was getting copied into .data, so my program was using t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
    [main.cc]
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2019-01-24 Startup mostly works -- doesn't correctly set up A3000 from cold boot, but runs in Arculator and starts if switched to after RO3 has already booted
    [main.cc]
2019-01-28 Text display works on pre-memory startup. Added start of BCD conversion, so we can print numbers too.
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2019-02-05 Risc PC adapter for Arcflash
    [riscpc_adapter.kicad_pcb]
2019-02-06 Tidied silkscreen and edges, and brought bottom right edge in a bit
    [riscpc_adapter.kicad_pcb]
2019-02-07 Moved a bunch of tracks to the bottom copper layer, to make room between them.
    [riscpc_adapter.kicad_pcb]
2019-02-07 More messing around with traces on riscpc adapter board
    [riscpc_adapter.kicad_pcb]
2019-02-07 Looking nice -- time for staples
    [riscpc_adapter.kicad_pcb]
2019-02-07 Added tons of staples
    [riscpc_adapter.kicad_pcb]
2019-02-08 a whole lot more staples
    [riscpc_adapter.kicad_pcb]
2019-02-08 Realized I got the RPC ROMs backwards, so need to reroute or fix in software
    [riscpc_adapter.kicad_pcb]
2019-02-08 v1, ready to go to JLC
    [riscpc_adapter.kicad_pcb]
2019-02-08 v1 ready to go to JLC
    [a5000_adapter.kicad_pcb]
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2019-02-12 Realized I can skip all the << 16 stuff by just making all IOC regs uint8_t*. More attempts to make keyboard init properly.
    [main.cc]
2019-02-17 Starting on v2: renamed arc_RESET pin to rom_nOE and added jumper to connect LA21 to rom_A19
    [a3000_rom_emulator.kicad_pcb]
2019-02-17 v2: 74lvt125 added and all lines routed, I think
    [a3000_rom_emulator.kicad_pcb]
2019-02-17 Added decoupling cap for BUF
    [a3000_rom_emulator.kicad_pcb]
2019-02-17 Added 1 and > graphics to make assembly easier
    [a3000_rom_emulator.kicad_pcb]
2019-02-19 Switch stb_sprintf over to 32-bit integers so we don't need __aeabi_uldivmod, and make everything use display_printf rather than many display_print_* calls.
2019-03-16 Arcflash RISC PC support -- the bootloader now includes a cut-down version of RISC OS, and boots on both Archimedes and RISC PC machines.
2019-04-28 Fix bug with padding -- it was only showing up when I had three 4MB images
    [rombuild.py]
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2019-06-12 Arcflash-A v2 final; from a couple of weeks ago
    [a3000_rom_emulator.kicad_pcb]
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2019-09-08 Arcflash: initial v2 firmware support; moved libxsvf from libraries to src, to experiment with building under the Arduino IDE.
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2019-09-13 Successfully detecting RESET double-clicks, and resetting machine when OS selected in bootloader
    [firmware.ino]
2019-09-14 Now always doing a power on reset into a selected OS (also POR works!)
    [firmware.ino]
2020-05-16 Switch to Python 3, and correctly mirror bottom silkscreen when rendering Gerbers
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2020-07-17 arcflash: v3 PCB with 68R resistor packs to provide some protection/damping to data lines
    [a3000_rom_emulator.kicad_pcb]
2020-07-25 arcflash: Rename cpld_MOSI_sync to cpld_TXD_sync; make it harder to fail to enable comms because bitbang serial is enabled
    [a3000_rom_emulator.v]
2020-07-25 arcflash: Make it possible to single or double sync Romcs*; doesn't appear to save any CPLD space though
    [a3000_rom_emulator.v]
2020-07-25 arcflash: Remove reset_arm and uncomment SPI logic gated by enable_comms
    [a3000_rom_emulator.v]
2020-07-25 arcflash: Add an option to sync SPI signals to the 48MHz clock (fitting fails with this enabled)
    [a3000_rom_emulator.v]
2020-07-28 arcflash: Switch bootloader byte order too; verified that this works on my A5000
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2021-01-20 arcflash: Add custom bootloader so we can use our own USB VID/PID
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2021-01-20 arcflash: Add troubleshooting notes for firmware build, crash out on build errors, and use a better board-specific define
    [build_and_upload.py]
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2025-02-04 Include correct copyright line in third_party/arm-trusted-firmware/LICENSE
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2025-03-18 firmware: send OK in response to unknown chars, so ROM uploads don't get stuck at first
    [firmware.ino]
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2025-03-19 Reduce host/MCU serial baud rate to 25000 and rewrite bit banged sender.
    Serial traffic at 57600 was unreliable -- the MCU would see a framing
    error every 100 chars or so, due to ~7 us jitter that accumulated over
    a character sometimes. Reducing baud rate to 25000 makes it pretty
    solid.
    [firmware.ino, main.cc]
2025-03-19 firmware: Replace unnamed enum with an scoped enum
    [firmware.ino]
2025-03-20 firmware: Completely replace lib folders if we're doing a clean build
    [build_and_upload.py]
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2025-03-21 Fix bit-bang serial reception.
    The missing IOC_TIMER1_GO line in read_serial_byte() was causing the
    incoming bits to be sampled right as they were changing, which was
    extremely unreliable.
    [firmware.ino, main.cc]
2025-03-23 cpld: Fix cocotb warnings
    [arcflash_test.py]
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2025-04-04 pcb: Update to KiCad 9, fix Makefile to build fab outputs again
    [a3000_rom_emulator.kicad_pcb, riscpc_adapter.kicad_pcb]
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2025-04-07 os_switcher_bootloader: Use tag name from GitHub, or short git ref, as version
    [main.cc]
2025-04-09 os_switcher_bootloader: Build under -Wall -Werror, correctly align version in screen header
    [main.cc]
2025-04-09 firmware: Delete old commented out code, fix endian comment
    [firmware.ino]
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
